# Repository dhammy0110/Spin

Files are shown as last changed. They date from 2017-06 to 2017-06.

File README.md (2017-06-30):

# Spin Turntable with AccelStepper motor control

Based off of the Spin project from Tiffany Tseng (https://github.com/ttseng/Spin), this fork contains the following changes:
// replaced motor driver with smoother AccelStepper movements
// deleted vestigial code and moved created rotateAndPhoto method to clean up main loop
// replaced Processing debug with native Arduino serial interface
// tuned controller to work with Spin ios app as it is.
// added Easy Button button switch to circuit schematic

If you wish to build, please check out the great instructions at the original project site http://spin.media.mit.edu/

## Arduino

This folder contains the SoftModem & AccelStepper libraries needed for the spin.ino Arduino sketch.  The spin sketch should be uploaded to the Arduino Uno running the Spin app.

## CAD

If you are building a turntable and have access to a laser cutter with a bed larger than 12", build the DEFAULT turntable. If you have a smaller laser cutter that cannot cut material larger than 12", build the Modified 12-inch turntable design.  Both designs have the same exact footprint (13"), but the modified 12-inch turntable has smaller laser cut parts and has an additional set of three 3D printed feet.

Each contains three subfolders: _3D Print_, _Laser Cut_, and _Solidworks_.  Building your own Spin turntable requires laser cutting parts in 3/16" and 1/8" acrylic, which can be found in the _Laser Cut_ folder in Illustrator, Corel Draw, and DXF formats.  Additionally, you'll need to 3D print a gear (motor_gear.STL), which can be found in the _3D print_ folder.  Optionally, you can 3D print your own iOS device dock (which can be used with an iPhone 4/5/6 or iPad/iPad mini).  If you are building the modified turntable, you will also need to 3D print three feet.  

You can find all the original CAD files in the _Solidworks_ folder.

## Electronics

The Eagle files and libraries for the original Spin shield are located here, as is the schematic for the DIY shield. You can purchase the shield directly from OSH Park: https://oshpark.com/profiles/scientiffic or solder your own DIY shield

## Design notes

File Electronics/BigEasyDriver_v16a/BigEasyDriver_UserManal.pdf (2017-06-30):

# Big Easy Driver User Manual

Doc version 1.2, for BED v1.2 11/04/2012
Brian Schmalz
Schmalz Haus LLC
www.schmalzhaus.com/BigEasyDriver brian@schmalzhaus.com

### Description

The Big Easy Driver (BED) is a major revision of the Easy Driver stepper driver board. The BED takes power and control signals (STEP and DIRECTION) and produces the signals necessary to step a 0A to 2Amp bi-polar stepper motor. The BED uses an Allegro A4983 or A4988 driver chip.

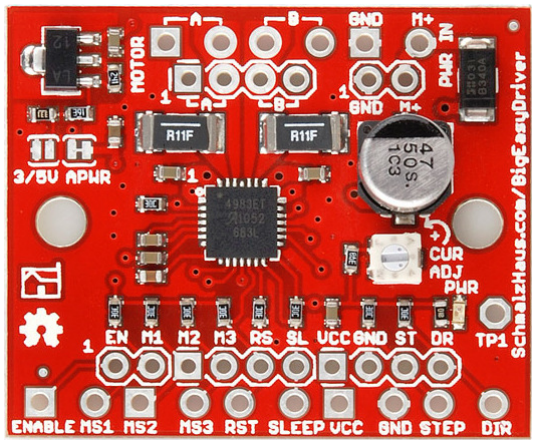
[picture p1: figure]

Figure 1: Big Easy Driver v1.2

### Hook Up

The BED has holes for both .100 headers as well as 3.5mm screw terminals. Either or both can be used to connect to the BED however you want. You can put female or male headers in the .100” holes or solder wires directly to the holes.

The minimum number of connections to the BED is 7 – four stepper wires, Power, Gnd and Step. All others are optional. Note that there are two ground connections – one next to the power input, and one next to the step input. Typically these will connect to the power supply ground and the signal ground (from the microcontroller) respectively.

Top Edge Connections

Motor: Connect the four wires from the motor to the four motor connections on the BED. The two “A” connections should connect to one coil, and the “B” connections to the other coil.

Power: Connect the power input (+8 to +30V filtered DC) to the M+ connection, and GND from the power supply to the GND connection.

Bottom Edge Connections
ENABLE: This input is pulled down on the board with a 20K Ohm resistor. You can leave it disconnected, or you can drive it from your microcontroller. When low, the driver chip is enabled and the motor is energized. When high, the driver chip is still enabled, but all of the final motor drive circuits are disabled and so no current will flow to the motor.

MS1, MS2, MS3: These inputs are all tied high with 20K Ohm resistors. They set the microstep setting. Use the following table to know how to control the microstep settings:
MS1 | MS2 | MS3 | Microstep Resolution | Excitation Mode
L | L | L | Full Step | 2 Phase
H | L | L | Half Step | 1-2 Phase
L | H | L | Quarter Step | W1-2 Phase
H | H | L | Either Step | 2W1-2 Phase
H | H | H | Sixteenth Step | 4W1-2 Phase

RST: (Reset) This input is tied high with a 20K Ohm resistor on the BED. If this signal is pulled low, the motor driver circuits are shut off, and the driver is reset. Only when this input is high will the driver chip enable the motor driver circuits and pay attention to the STEP input.

SLEEP: This input is tied high with a 20K Ohm resistor on the BED. To put the driver chip into a lower power mode (motor driver circuits shut off, charge pump shut down, etc.) pull this input low. When coming out of sleep, allow at least 1ms before sending STEP pulses.

VCC: This is an output from the BED’s voltage regulator. The voltage regulator takes the motor input voltage, and provides 5V (or 3.3V) for the logic inputs of the driver chip. You can normally use about 85mA from this pin, although the higher the motor input voltage is, the hotter the voltage regulator chip will get as you pull more current from this pin. See the jumper configuration section below to switch this to 3.3V output.

GND: This is one of two ground connections on the BED. The other is on the topside next to the M+ power input. Both grounds are internally tied together on the BED. This is a good place to tie the ground of your microcontroller.

STEP: This input is tied high with a 20K Ohm resistor on the BED. Each rising edge of this input will cause the stepper driver to advance one step in the direction specified by the DIR input. The STEP input must be high for at least 1us, and low for at least 1us.

DIR: This input is tied high with a 20K Ohm resistor on the BED. When a STEP pulse is received, the driver chip looks at this input to determine which direction to take the step. When high, the motor will turn counterclockwise, and when low, the motor will turn clockwise.

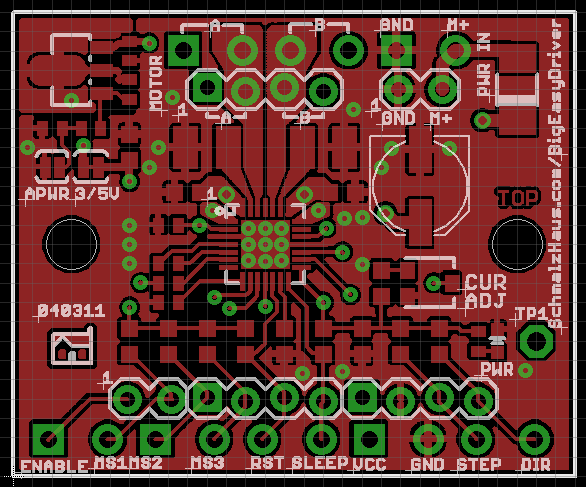
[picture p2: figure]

Figure 2: BED v1.1 Connection Placement Diagram

### Jumper Configuration

There are two jumpers on the BED – APWR (Alternate Power) and 3/5V. They are located in the upper left corner of the BED.

NOTE: On the v1.1 of the BED these two jumpers have their silk screen labels reversed.

APWR (Alternate Power) – This jumper is normally closed (connected). If you cut the trace between the two pads, the BED’s voltage regulator chip is disconnected from the circuit, and you can then use the VCC connection on the bottom edge of the board as an input, to power your BED with whatever logic level voltage you want to. (3.0V to 5.5V is the accepted range.) You might choose this option if you wish to power your BED’s logic level circuits with an external power source. This jumper is labeled SJ1 in the schematic.

3/5V – This jumper is normally open (dis-connected). You can switch the BED to use 3.3V for its logic level circuits by soldering this jumper closed. You would do this if you wanted to interface your BED to a 3.3V microcontroller for example. This jumper is labeled JS2 in the schematic.

### Current Limit Set Potentiometer

The BED includes a very small pot to allow for the adjustment of the maximum current level through the windings of the motor. On the board, this pot is labeled CUR ADJ. Turning changes the Vref voltage into the A4988 driver chip, and thus changes the maximum current that the driver chip delivers to the motor coils. Note that on v1.2 BED boards the silk screen arrow indicating which direction increases current to the motor is backwards. Use TP1 to determine maximum and minimum current directions to be sure.

The TP1 testpoint can be used to measure the voltage on the CUR_REF net, which the driver chip uses to determine the maximum current through the motor. Use your volt meter to measure the voltage on TP1 with respect to GND as you turn the pot.

If your BED uses .22 ohm sense resistors (some v1.1 BEDs): The range of the pot produces maximum motor currents from around 0mA (fully clockwise) to 2.4A (fully counterclockwise).

If your BED uses .11 ohm sense resistors (all v1.2 and above BEDs): The range of the pot produces maximum motor currents from around 0mA (fully clockwise) to 5A (fully counterclockwise). Now, the driver can’t supply 5A, so the full range of the pot won’t be used. A Vref of 1.76V will result in a motor current of 2A.

The equasion for this relationship is
Itripmax = Vref/(8 * Rs)
Where Itripmax is the maximum current delivered to the motor, Vref is the voltage on TP1, and Rs is the sense resistor value.

### Power LED

There is a yellow LED near the lower left corner of the BED labeled PWR. This LED will light any time there is 5V or 3.3V being supplied to the driver chip. If this LED goes off while there is still power being applied to the M+ and GND power inputs, then the voltage regulator chip has either become too hot and shut down, or has detected a short from VCC to GND and has shut off. If the LED turns on and off, then either the M+ power is turning on and off, or the voltage regulator chip is overheating and power cycling to try and stay cool

### Heat Dissipation

The Big Easy Driver can supply up to about 1.4A/phase of current at room temperature. This is due to the four layer construction of the board and the way the board is laid out. When driving high currents, the entire board will act as a heatsink, including the connectors and anything the board is connected to. The driver chip has excellent over temperature protection, so no damage can be done to the driver chip by running the board too hot – it will simply cut out until the chip temperature returns to normal (less than about 150C).

Adding a small heatsink (like Newark 43M6428) and/or using a small fan to cool the drive chip can allow currents in excess of 2A/phase.

### Motor Wiring

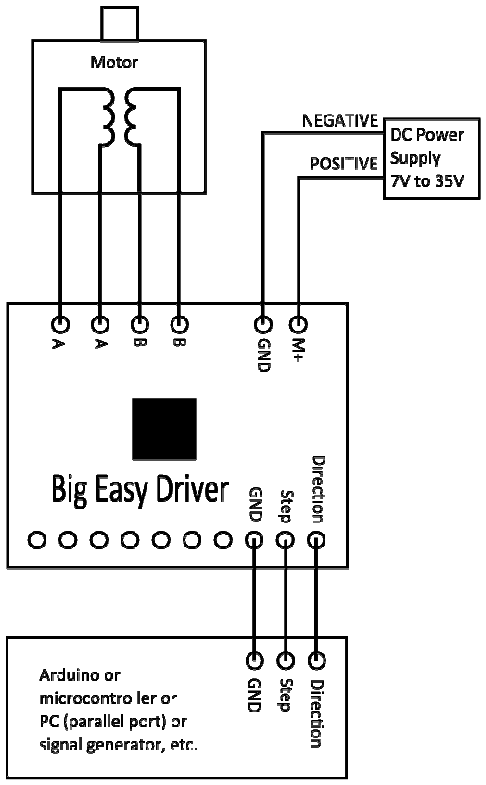
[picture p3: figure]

This diagram shows a typical connection (actually, the bare minimum connection) for a BED with a stepper motor and a source for step/direction signals. Of course, you can always connect more of the digital input signals on the BED (SLEEP, MS1, etc.) for more control.

### Specifications

The specifications of the Big Easy Driver are the same as for the Allegro A4983 or A4988 stepper driver chip (depending upon which is installed on the board). This includes a maximum of 2A/phase, 16th, 8th, ¼, ½ and full step modes, 3.3V or 5V logic inputs (jumper selectable).

### Schematic

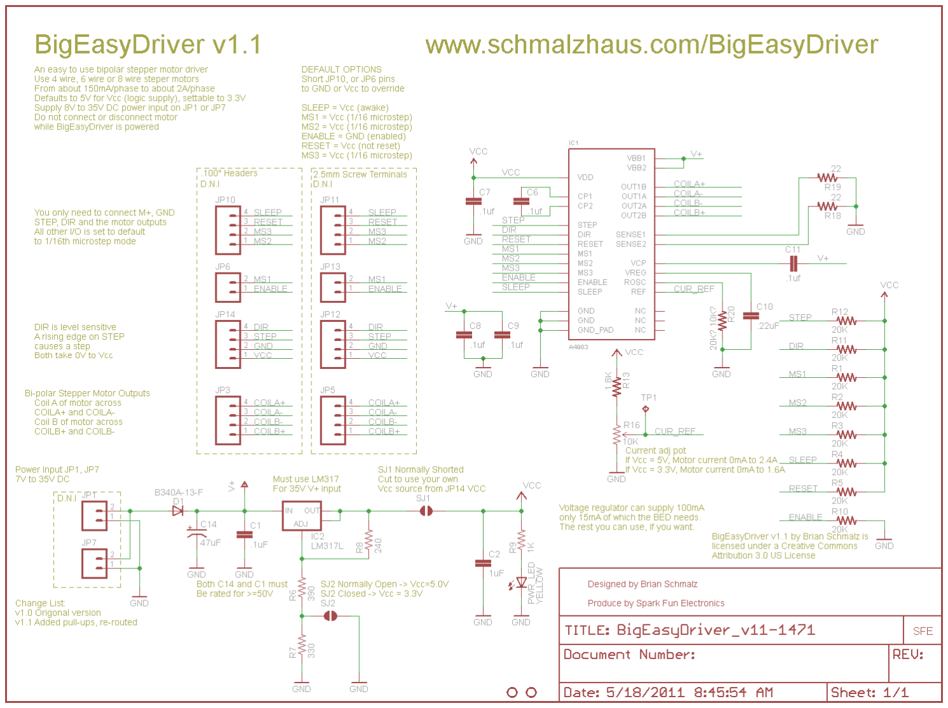
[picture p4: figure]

### Parts Placement

This user manual is only an overview. For more information about the technical details of how the BED drives the stepper motor, please see the official Allegro A4983 or A4988 driver datasheet. www.allegromicro.com

### License

This document, and the entire BED design, are released under the Creative Commons Attribution 3.0 US License. This means that you may use it for whatever purpose you want, including commercial use, but you MUST give the original author (Brian Schmalz) proper attribution.

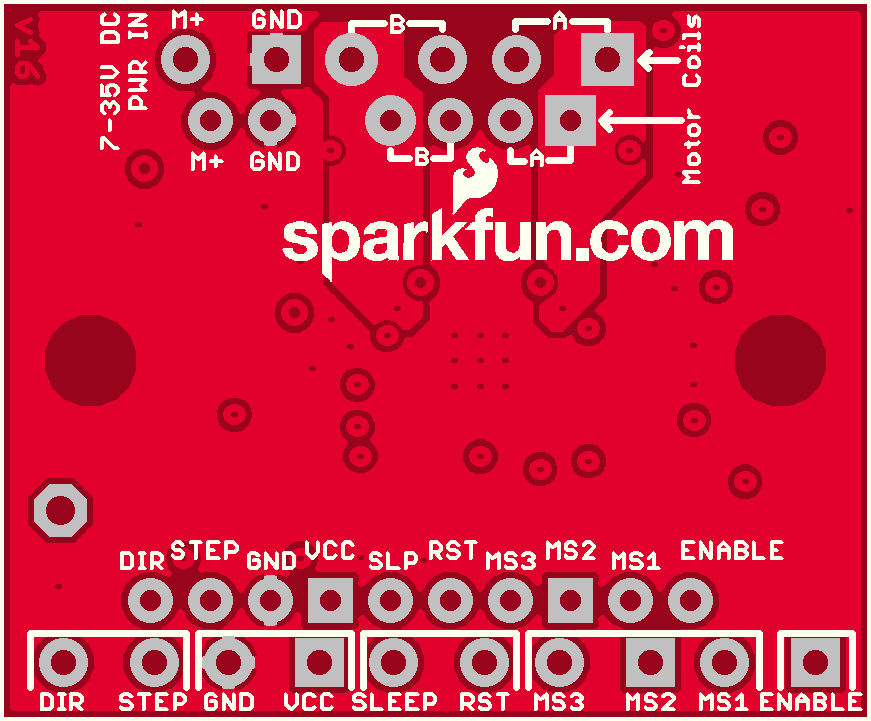
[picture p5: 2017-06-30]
Electronics/BigEasyDriver_v16a/BigEasyDriver_bottom_board.png

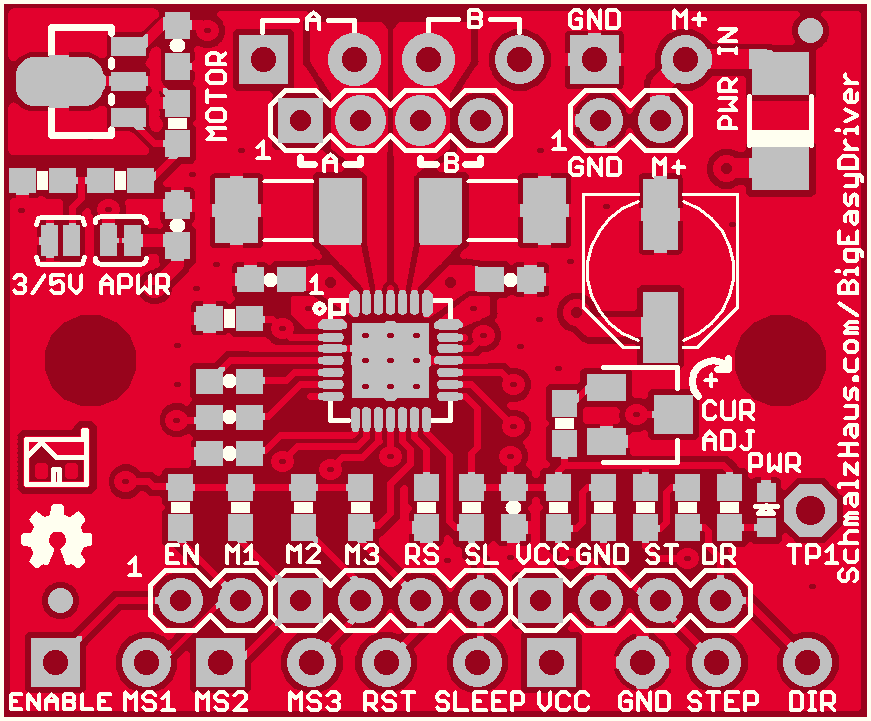
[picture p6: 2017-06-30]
Electronics/BigEasyDriver_v16a/BigEasyDriver_top_board.png

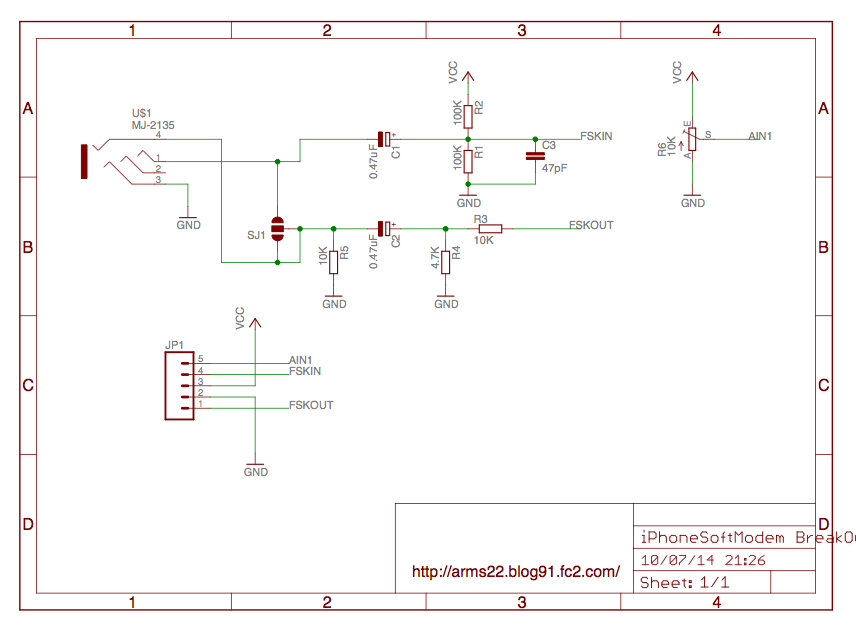
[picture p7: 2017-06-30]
Electronics/softmodem-circuit-schematic.png

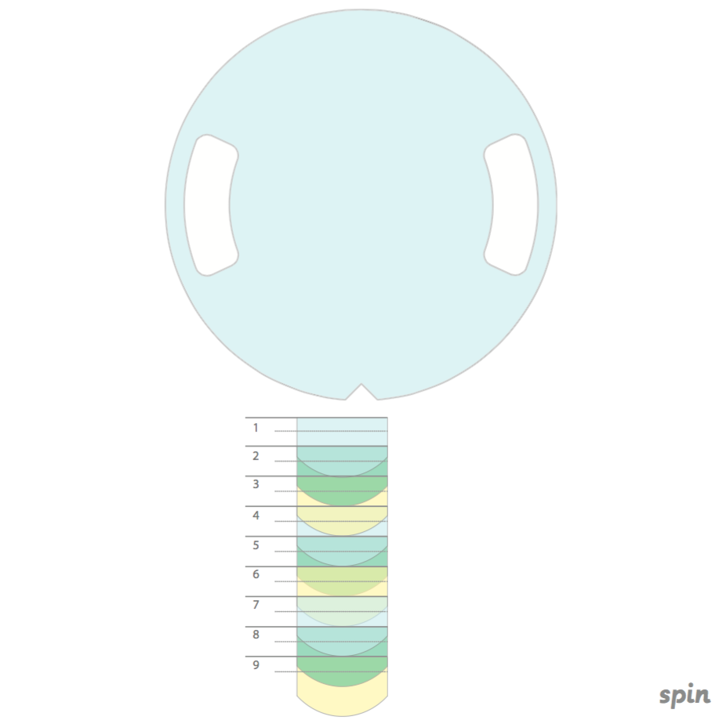
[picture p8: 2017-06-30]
CAD/Mat/mat.png

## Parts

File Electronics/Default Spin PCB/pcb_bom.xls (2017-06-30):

Item | Vendor | Quantity | Part Number | Total Price
Easy Drive Stepper Motor Driver | Sparkfun | 1 | ROB-12779 (https://www.sparkfun.com/products/12779) | 14.95
Blue LEDs 1206 SMD | Sparkfun | 1 (strip of 25) | PRT-12620 (https://www.sparkfun.com/products/12620) | 2.95
Male headers | Sparkfun | 2 | PRT-00116 (https://www.sparkfun.com/products/116) | 3
Female headers | Digikey | 1 | S5440-ND (http://www.digikey.com/product-detail/en/PPTC041LGBN-RC/S5440-ND/775898) | 0.63
3.5mm audio jack | Digikey | 1 | CP-43514-ND (http://www.digikey.com/product-search/en?KeyWords=CP-43514-ND&WT.z_header=search_go) | 1.18
100 Ω resistor 1206 SMD | Digikey | 4 | 311-100FRCT-ND (http://www.digikey.com/product-detail/en/0/311-100FRCT-ND) | 0.45
1 kΩ resistor 1206 SMD | Digikey | 2 | P1.0KECT-ND (http://www.digikey.com/product-detail/en/ERJ-8GEYJ102V/P1.0KECT-ND/203248) | 0.09
10 kΩ resistor 1206 SMD | Digikey | 1 | 311-10.0KFRCT-ND (http://www.digikey.com/product-detail/en/RC1206FR-0710KL/311-10.0KFRCT-ND/731430) | 0.09
0.22 µF 1206 capacitor | Digikey | 1 | 399-1251-1-ND (http://www.digikey.com/product-search/en?KeyWords=399-1251-1-ND&WT.z_header=search_go) | 0.17
 |  |  |  | Total: $23.51

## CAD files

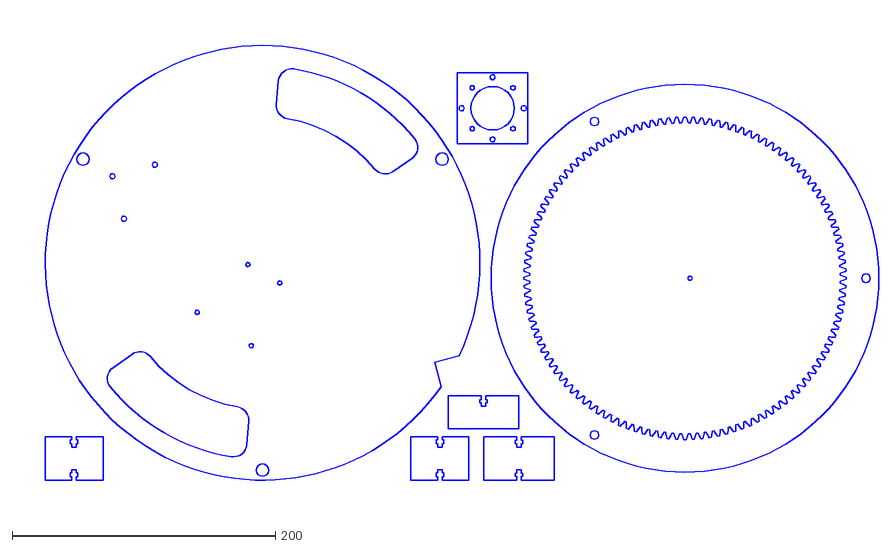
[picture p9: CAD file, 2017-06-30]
CAD/DEFAULT turntable/Laser Cut/SpinSmoothly-rearranged.dxf
655.5 x 374.2

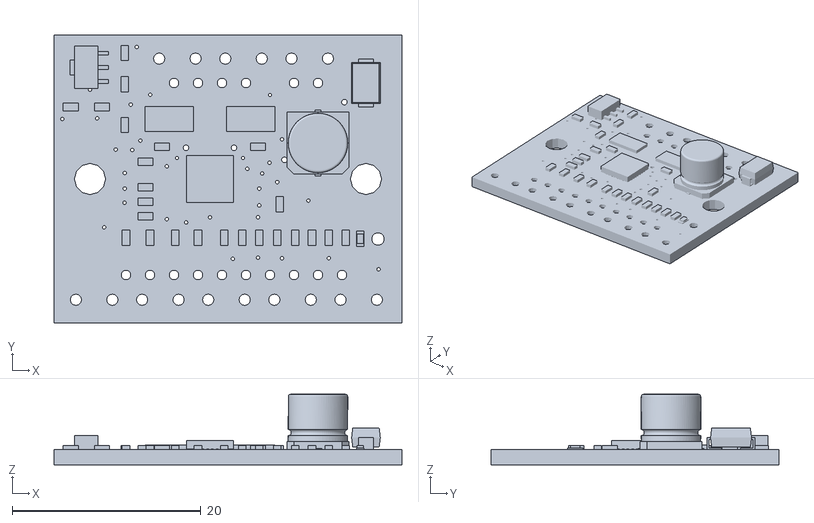
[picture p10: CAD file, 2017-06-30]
Electronics/BigEasyDriver_v16a/BigEasyDriver.stl
36.8 x 30.5 x 7.47

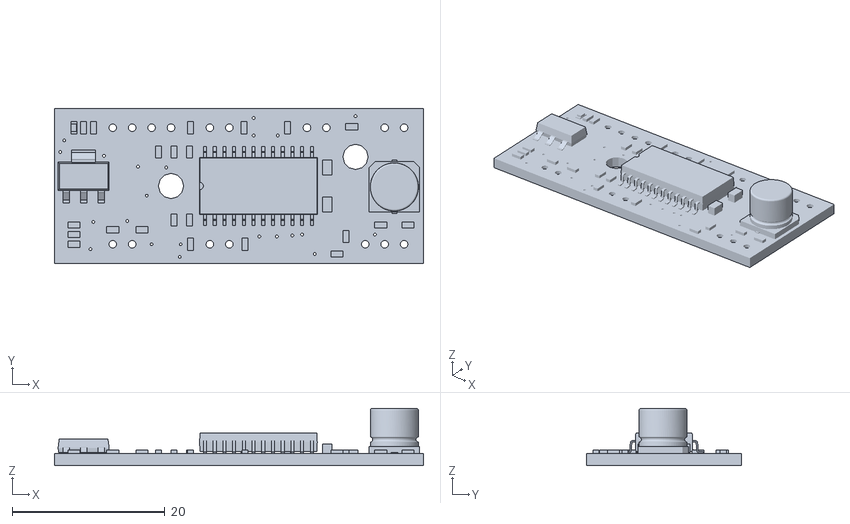
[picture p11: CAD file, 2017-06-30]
Electronics/Easy Driver/EasyDriver_v45-3DModel.stl
48.3 x 20.3 x 7.47

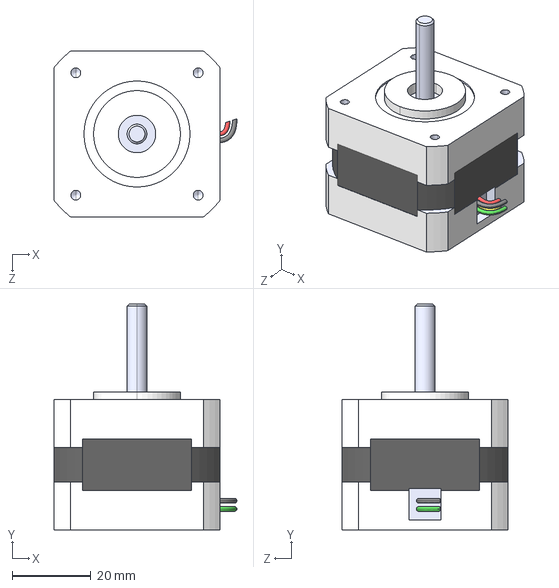
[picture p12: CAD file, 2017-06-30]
Electronics/Mercury Stepper Motor SM-42BYG011-25/Mercury Stepper Motor SM-42BYG011-25.STEP
46.3 x 57.2 x 42.0 mm

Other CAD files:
Electronics/BigEasyDriver_v16a/BigEasyDriver.blend
Electronics/BigEasyDriver_v16a/BigEasyDriver.skp
Electronics/Easy Driver/EasyDriver_v45-3DModel.skp
Electronics/Mercury Stepper Motor SM-42BYG011-25/Mercury Stepper Motor SM-42BYG011-25.IGS
Electronics/Mercury Stepper Motor SM-42BYG011-25/Mercury Stepper Motor SM-42BYG011-25.blend
Electronics/Mercury Stepper Motor SM-42BYG011-25/Mercury Stepper Motor SM-42BYG011-25.stl

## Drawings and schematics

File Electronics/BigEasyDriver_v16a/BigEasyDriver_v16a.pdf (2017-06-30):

# BigEasyDriver v1.6a

# www.schmalzhaus.com/BigEasyDriver

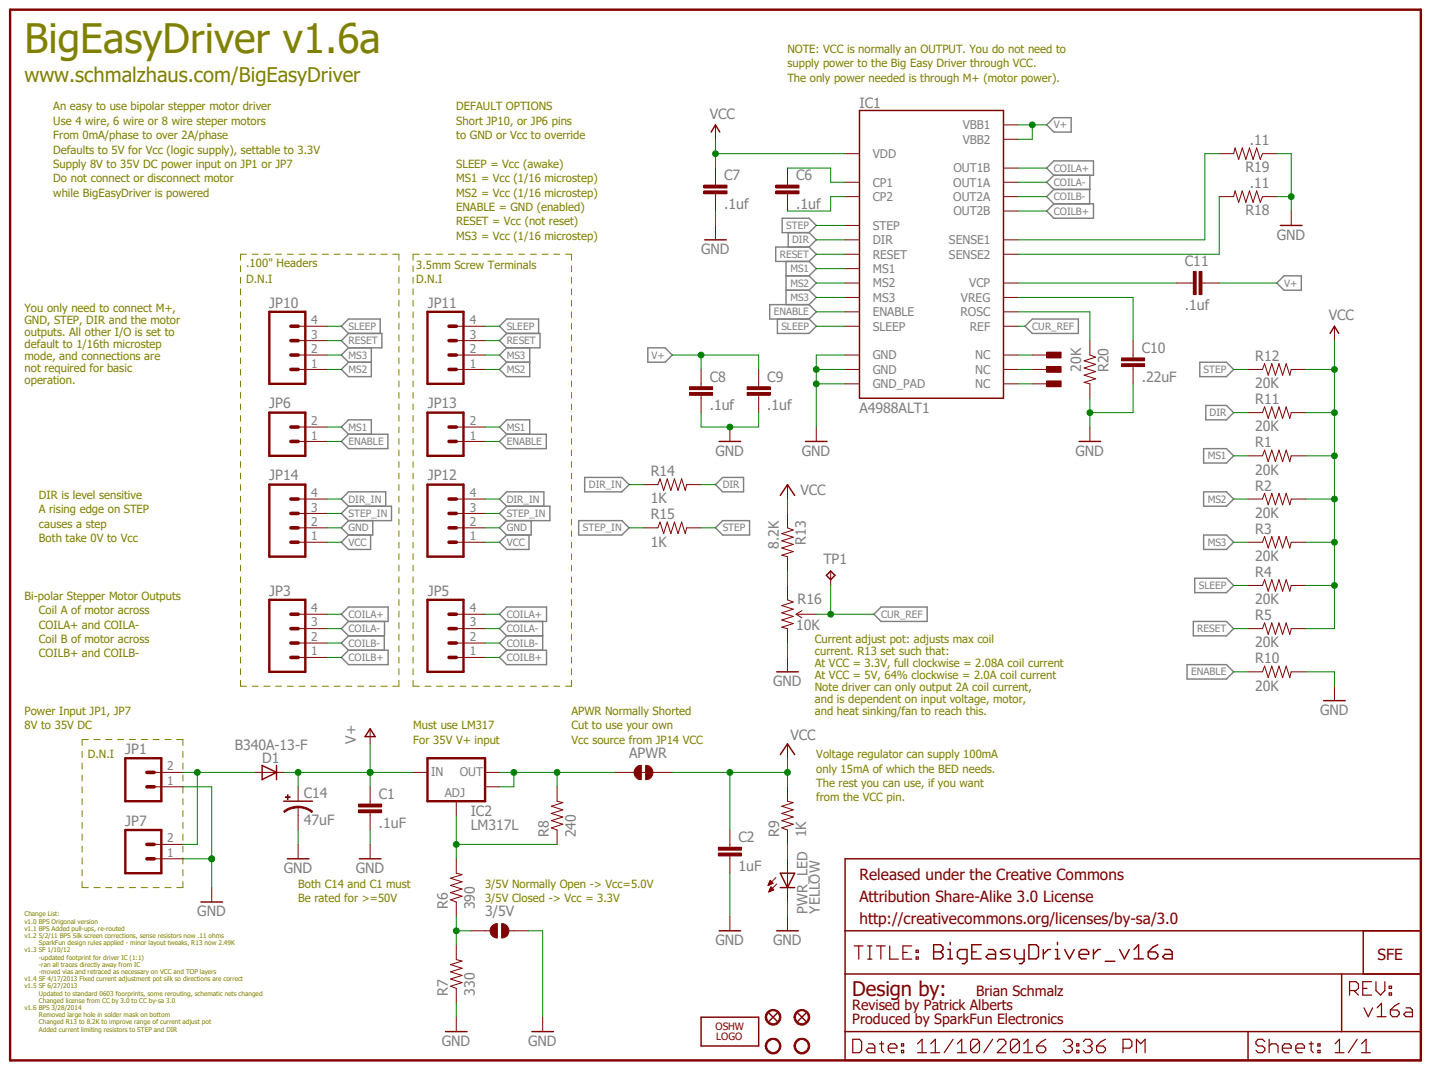
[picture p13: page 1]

NOTE: VCC is normally an OUTPUT. You do not need to
supply power to the Big Easy Driver through VCC.
The only power needed is through M+ (motor power).

An easy to use bipolar stepper motor driver
Use 4 wire, 6 wire or 8 wire steper motors
From 0mA/phase to over 2A/phase
Defaults to 5V for Vcc (logic supply), settable to 3.3V
Supply 8V to 35V DC power input on JP1 or JP7
Do not connect or disconnect motor
while BigEasyDriver is powered

DEFAULT OPTIONS
Short JP10, or JP6 pins
to GND or Vcc to override

SLEEP = Vcc (awake)
MS1 = Vcc (1/16 microstep)
MS2 = Vcc (1/16 microstep)
ENABLE = GND (enabled)
RESET = Vcc (not reset)
MS3 = Vcc (1/16 microstep)

You only need to connect M+,
GND, STEP, DIR and the motor
outputs. All other I/O is set to
default to 1/16th microstep
mode, and connections are
not required for basic
operation.

DIR is level sensitive
A rising edge on STEP
causes a step
Both take 0V to Vcc

Bi-polar Stepper Motor Outputs
Coil A of motor across
COILA+ and COILA-
Coil B of motor across
COILB+ and COILB-

Current adjust pot: adjusts max coil
current. R13 set such that:
At VCC = 3.3V, full clockwise = 2.08A coil current
At VCC = 5V, 64% clockwise = 2.0A coil current
GND

Note driver can only output 2A coil current,
and is dependent on input voltage, motor,
and heat sinking/fan to reach this.
VCC

APWR Normally Shorted
Cut to use your own
Vcc source from JP14 VCC

Voltage regulator can supply 100mA
only 15mA of which the BED needs.
The rest you can use, if you want
from the VCC pin.

Released under the Creative Commons
Attribution Share-Alike 3.0 License
http://creativecommons.org/licenses/by-sa/3.0

Change List:
v1.0 BPS Origonal version
v1.1 BPS Added pull-ups, re-routed
v1.2 5/2/11 BPS Silk screen corrections, sense resistors now .11 ohms
SparkFun design rules applied - minor layout tweaks, R13 now 2.49K
-updated footprint for driver IC (1:1)
-ran all traces directly away from IC
-moved vias and retraced as necessary on VCC and TOP layers
v1.4 SF 4/17/2013 Fixed current adjustment pot silk so directions are correct
Updated to standard 0603 foorprints, some rerouting, schematic nets changed
Changed license from CC by 3.0 to CC by-sa 3.0
v1.6 BPS 3/28/2014
Removed large hole in solder mask on bottom
Changed R13 to 8.2K to improve range of current adjust pot
Added current limiting resistors to STEP and DIR

SFE

Design by: Brian Schmalz Revised by Patrick Alberts Produced by SparkFun Electronics

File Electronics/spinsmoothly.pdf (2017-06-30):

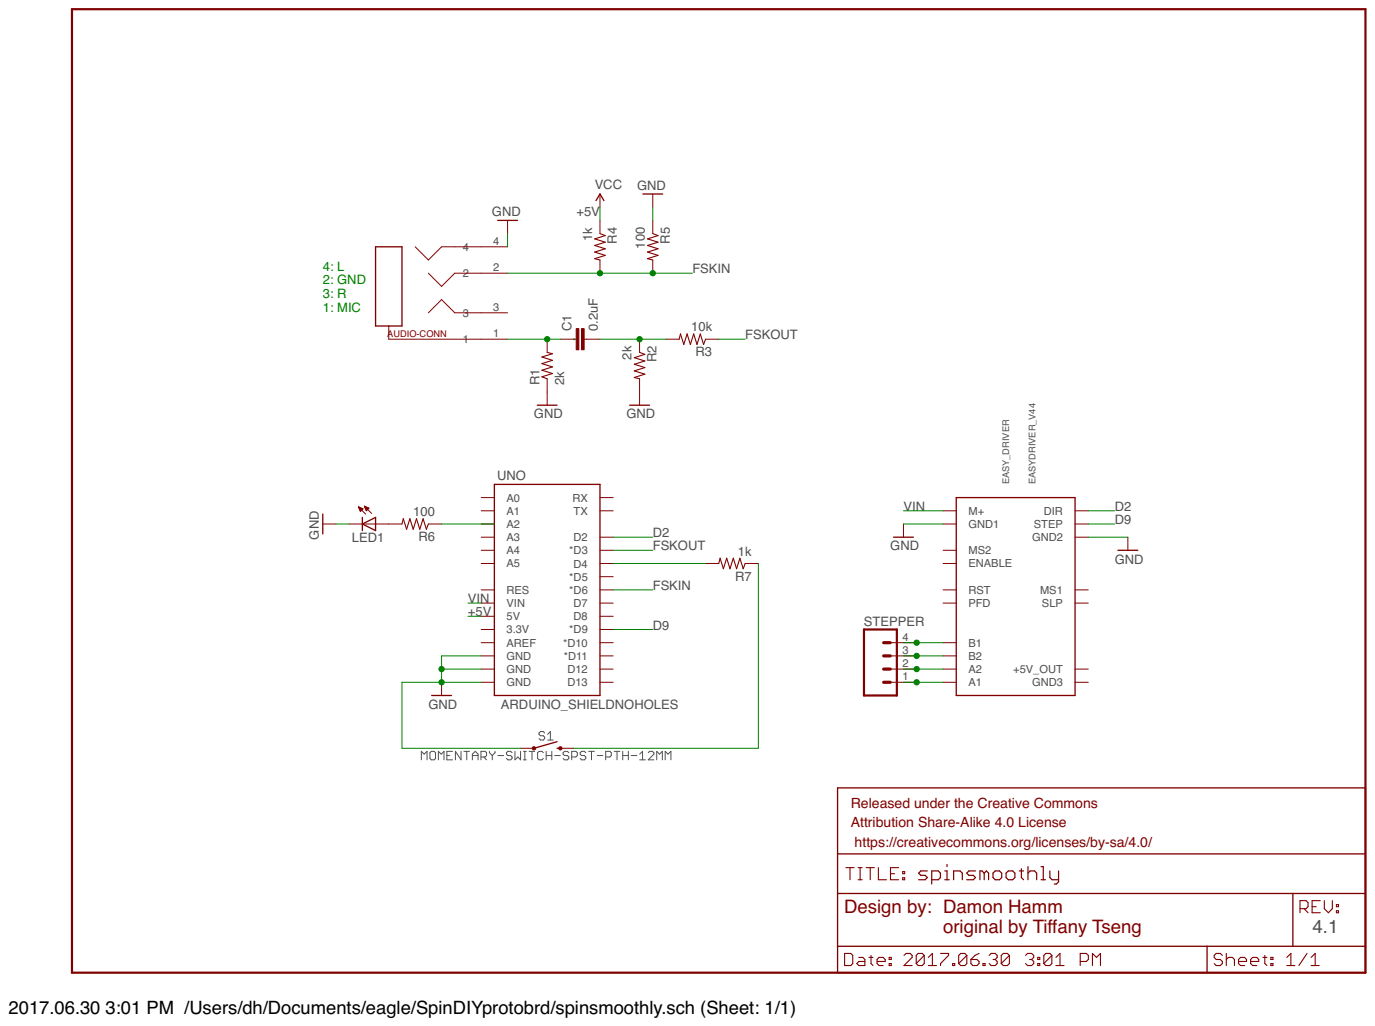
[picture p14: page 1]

Released under the Creative Commons Attribution Share-Alike 4.0 License

https://creativecommons.org/licenses/by-sa/4.0/

Damon Hamm
original by Tiffany Tseng

2017.06.30 3:01 PM /Users/dh/Documents/eagle/SpinDIYprotobrd/spinsmoothly.sch (Sheet: 1/1)

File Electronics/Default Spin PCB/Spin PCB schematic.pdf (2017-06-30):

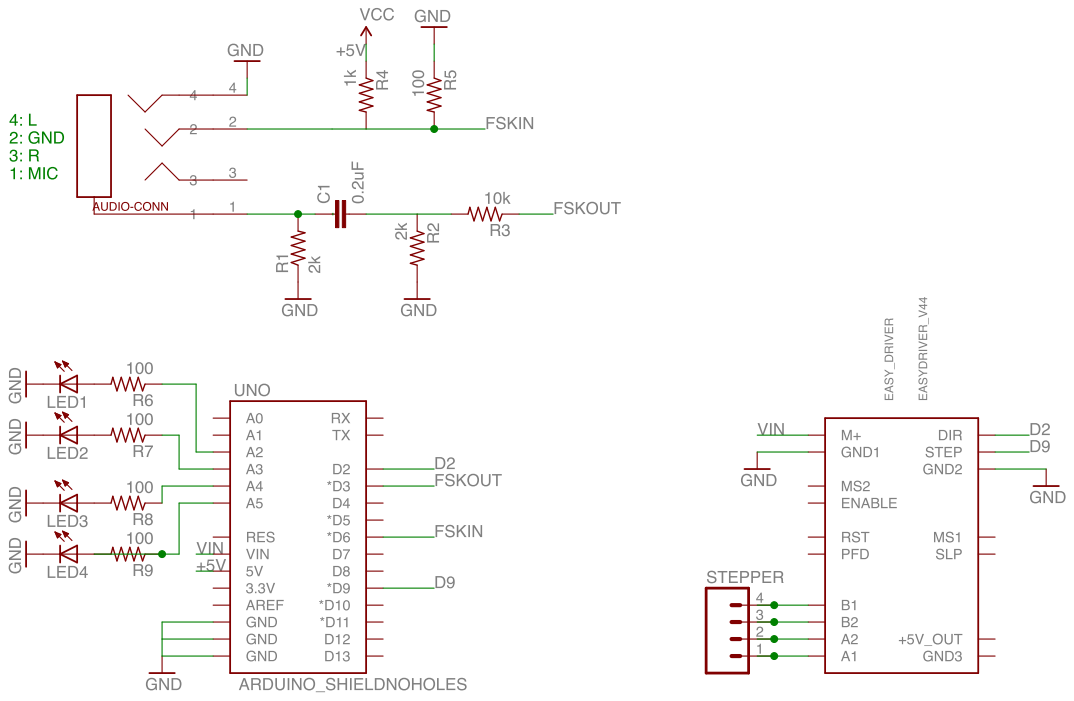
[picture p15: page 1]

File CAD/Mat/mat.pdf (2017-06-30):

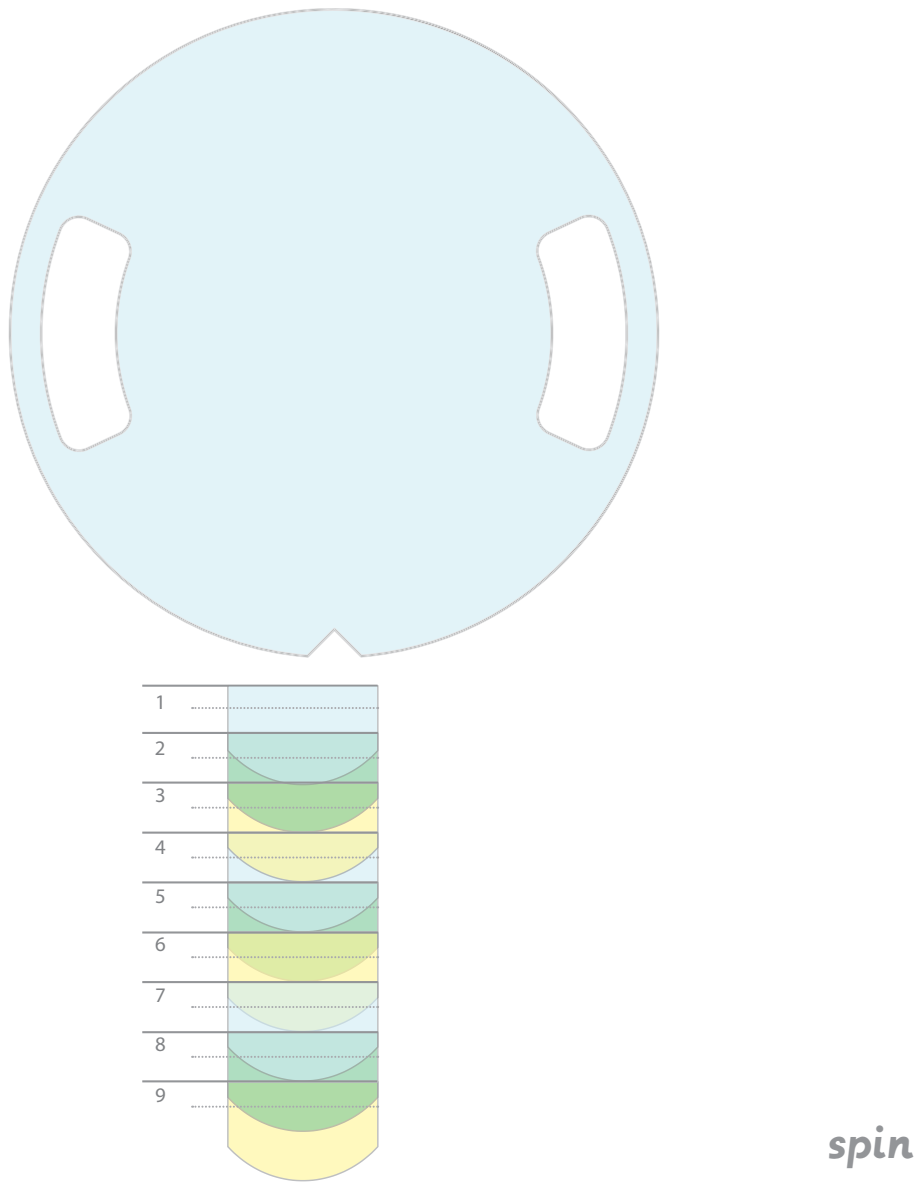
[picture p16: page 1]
spin

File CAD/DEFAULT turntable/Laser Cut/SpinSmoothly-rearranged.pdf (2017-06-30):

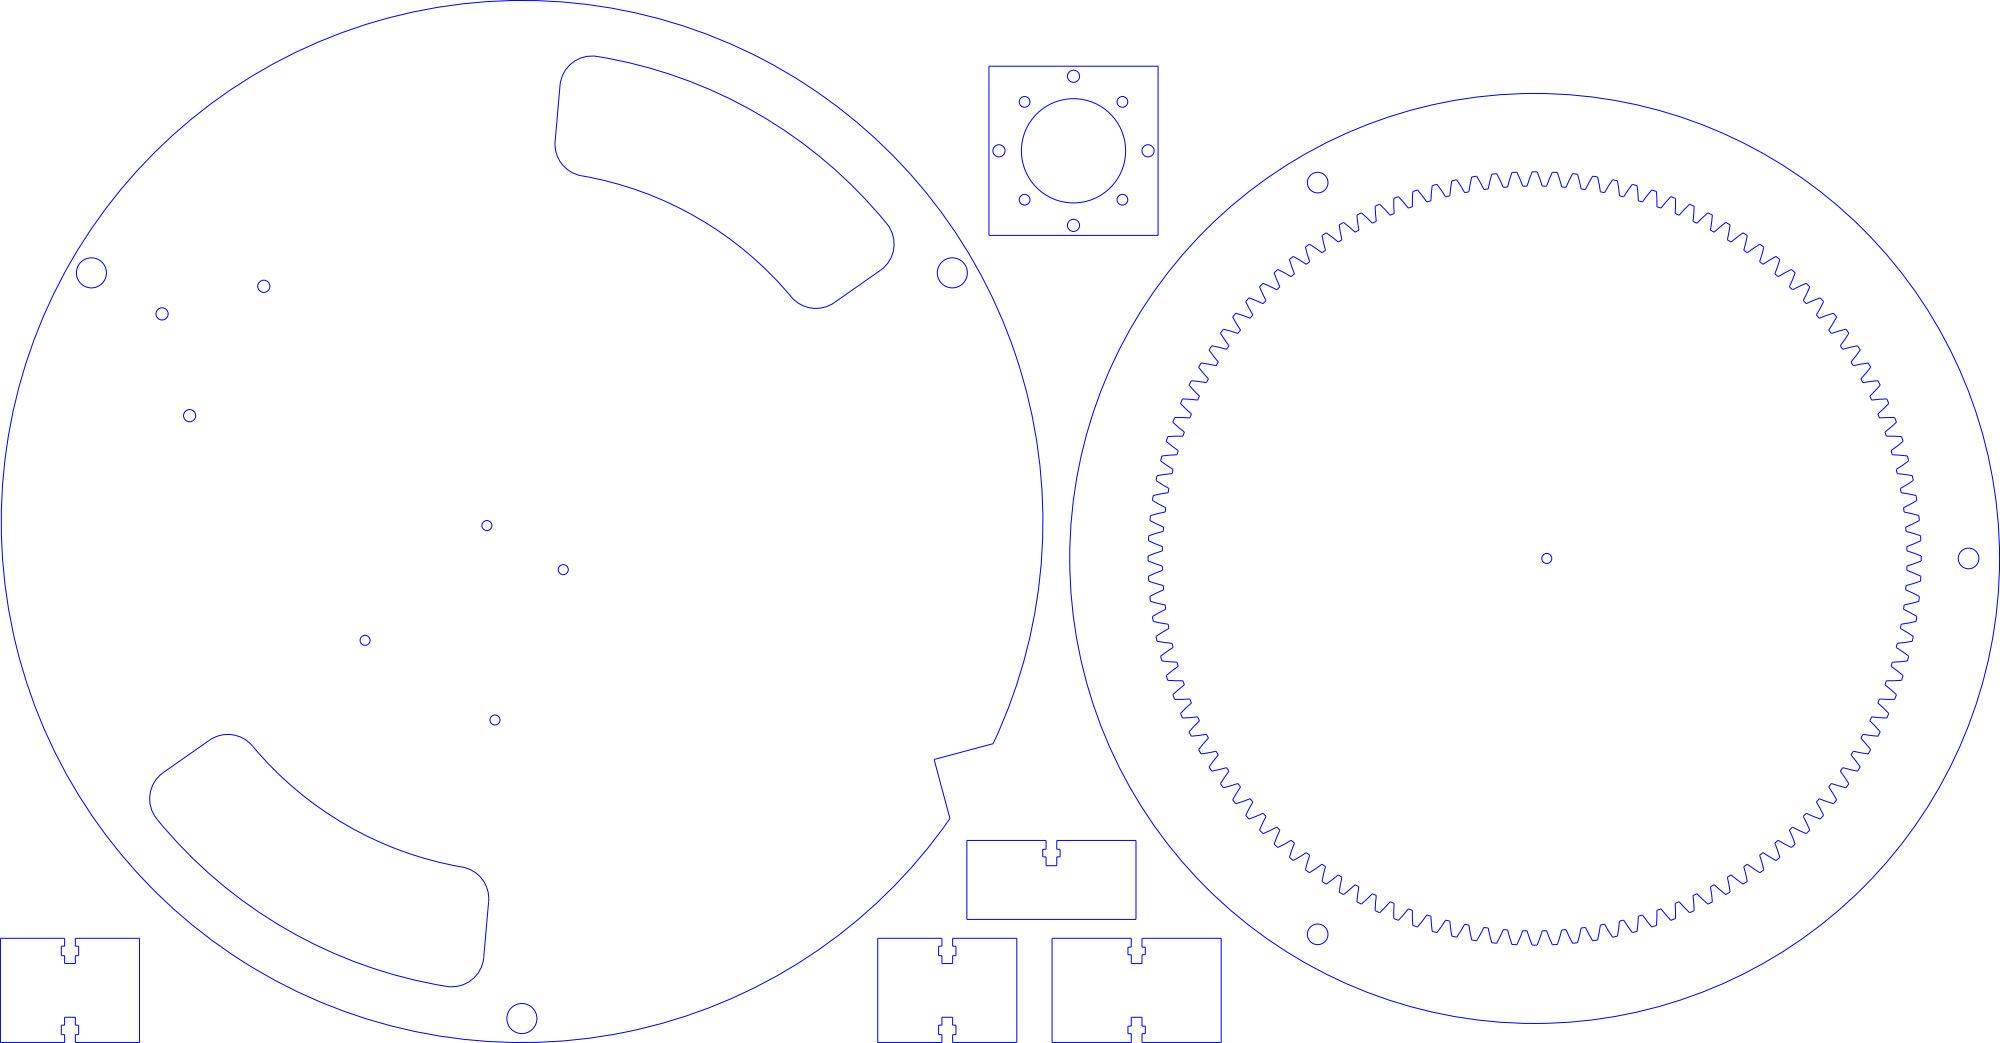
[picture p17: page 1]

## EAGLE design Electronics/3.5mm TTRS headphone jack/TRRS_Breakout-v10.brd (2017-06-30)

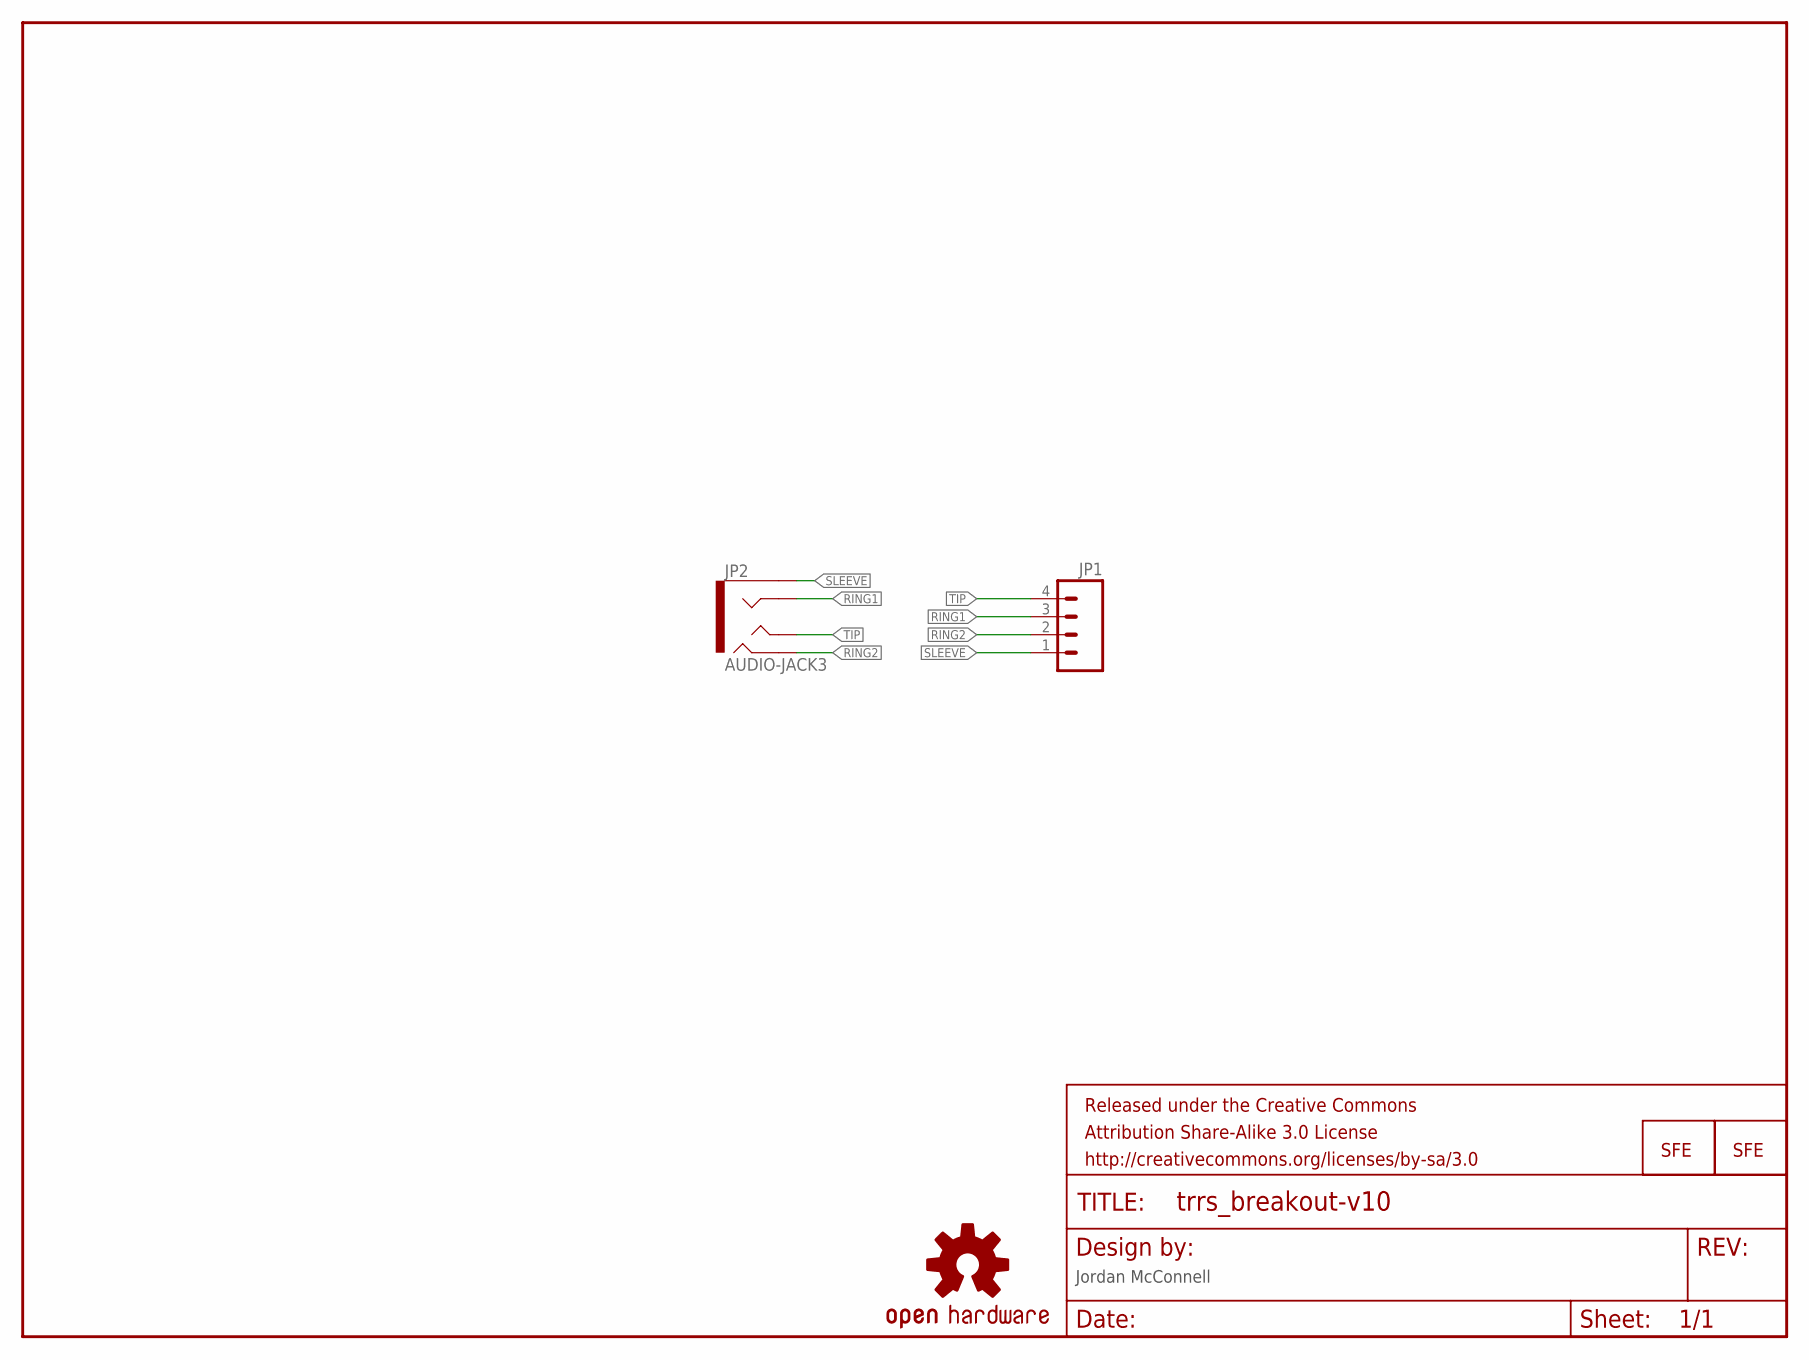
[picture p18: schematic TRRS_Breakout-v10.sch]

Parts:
FRAME1: FRAME-LETTER; CREATIVE_COMMONS
JP1: M04PTH; 1X04
JP2: AUDIO-JACK3; AUDIO-JACK-TRRS-SMD
JP3, JP4: LOGO-SFESK; SFE-LOGO-FLAME
U$1: OSHW-LOGOS; OSHW-LOGO-S

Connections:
RING1: JP1.3, JP2.RING1
RING2: JP1.2, JP2.RING2
SLEEVE: JP1.1, JP2.EARTH
TIP: JP1.4, JP2.TIP

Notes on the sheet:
Jordan McConnell

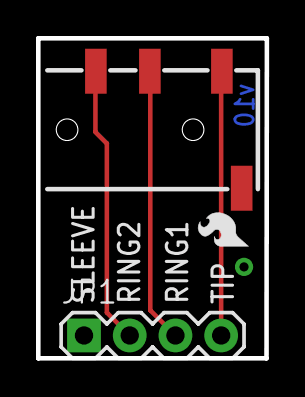
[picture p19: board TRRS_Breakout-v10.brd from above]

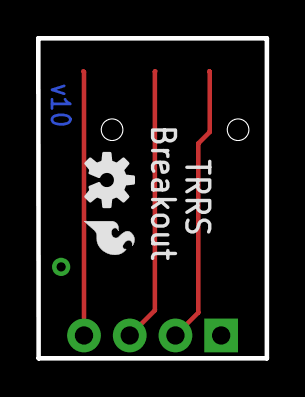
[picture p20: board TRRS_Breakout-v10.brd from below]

Board: 2 copper layers, 12.7 x 17.8 mm, 6 parts (2 on the bottom side), 4 nets.

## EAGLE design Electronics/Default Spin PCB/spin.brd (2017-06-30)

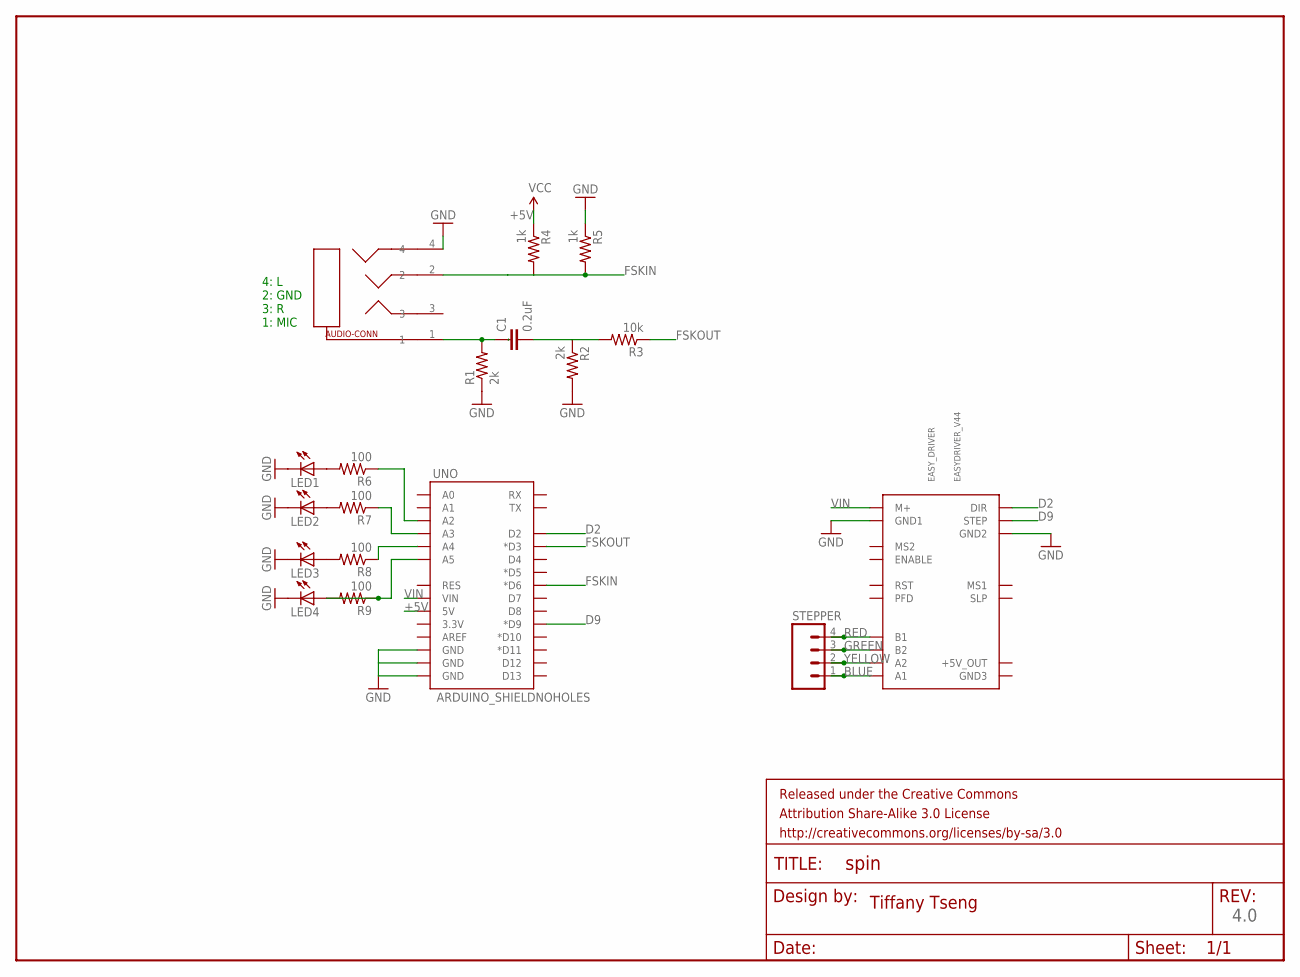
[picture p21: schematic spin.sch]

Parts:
C1: 0.2uF; 1206
EASY_DRIVER: EASYDRIVER_V44
FRAME1: FRAME-LETTER; CREATIVE_COMMONS
LED1, LED2, LED3, LED4: LED1206; 1206
R1, R2: 2k; R1206
R3: 10k; R1206
R4, R5: 1k; R1206
R6, R7, R8, R9: 100; R1206
STEPPER: M04PTH; 1X04
U$1: SJ-43514
UNO: ARDUINO_SHIELDNOHOLES; DUEMILANOVE_SHIELD_NOHOLES

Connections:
1: C1.1, R1.2, U$1.1
+5V: R4.1, UNO.5V
BLUE: EASY_DRIVER.A1, STEPPER.1
D2: EASY_DRIVER.DIR, UNO.D2
D9: EASY_DRIVER.STEP, UNO.D9 (*D9)
FSKIN: R4.2, R5.2, U$1.2, UNO.D6 (*D6)
FSKOUT: R3.1, UNO.D3 (*D3)
GND: EASY_DRIVER.GND1, EASY_DRIVER.GND2, LED1.2 (C), LED2.2 (C), LED3.2 (C), LED4.2 (C), R1.1, R2.2, R5.1, U$1.4, UNO.GND@0 (GND), UNO.GND@1 (GND), UNO.GND@2 (GND)
GREEN: EASY_DRIVER.B2, STEPPER.3
unnamed: C1.2, R2.1, R3.2
unnamed: R9.1, UNO.A5
unnamed: LED1.1 (A), R6.2
unnamed: LED2.1 (A), R7.2
unnamed: R8.1, UNO.A4
unnamed: LED3.1 (A), R8.2
unnamed: R7.1, UNO.A3
unnamed: LED4.1 (A), R9.2
unnamed: R6.1, UNO.A2
RED: EASY_DRIVER.B1, STEPPER.4
VIN: EASY_DRIVER.M+, UNO.VIN
YELLOW: EASY_DRIVER.A2, STEPPER.2

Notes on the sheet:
4: L 2: GND 3: R 1: MIC
4.0
Tiffany Tseng

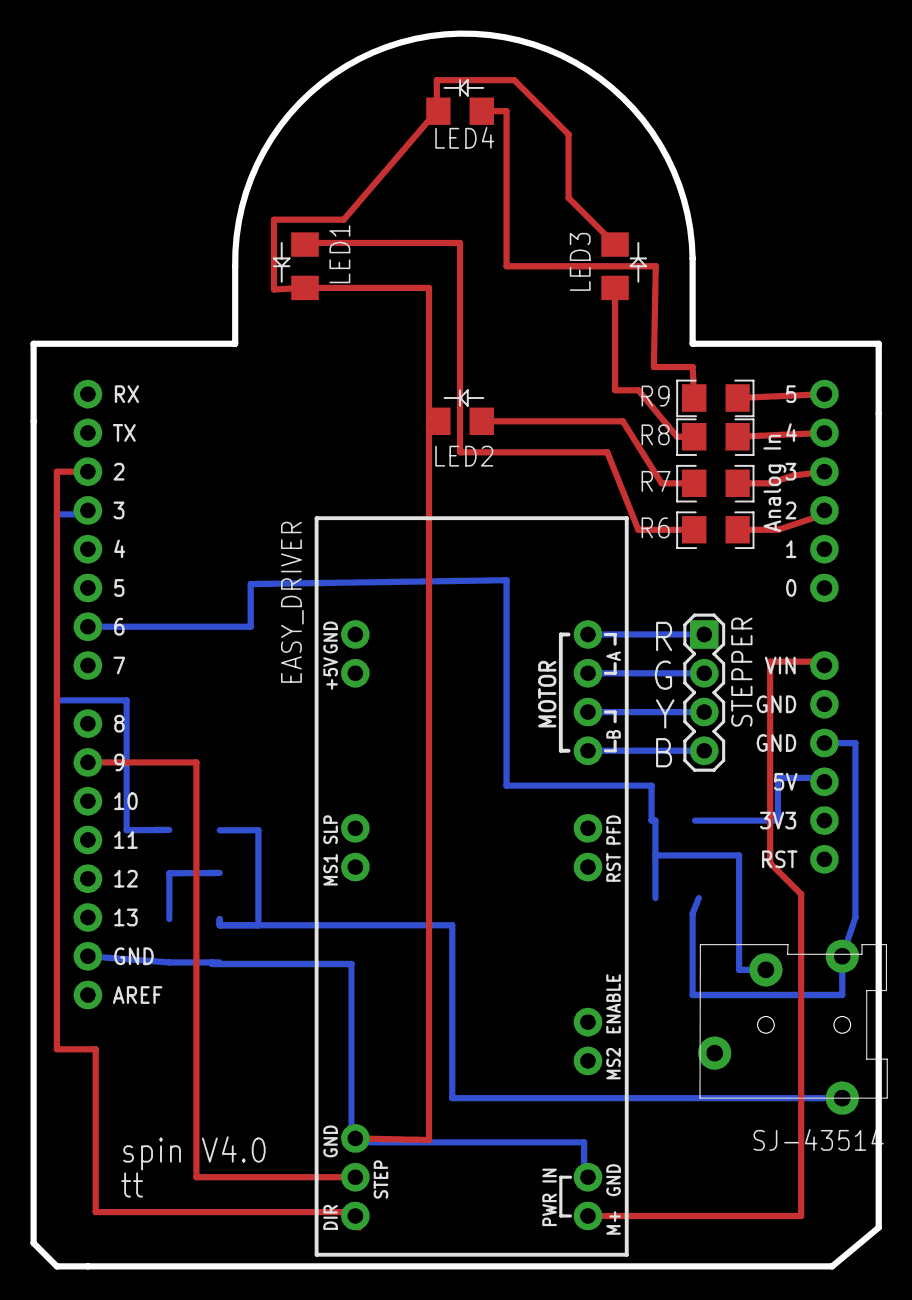
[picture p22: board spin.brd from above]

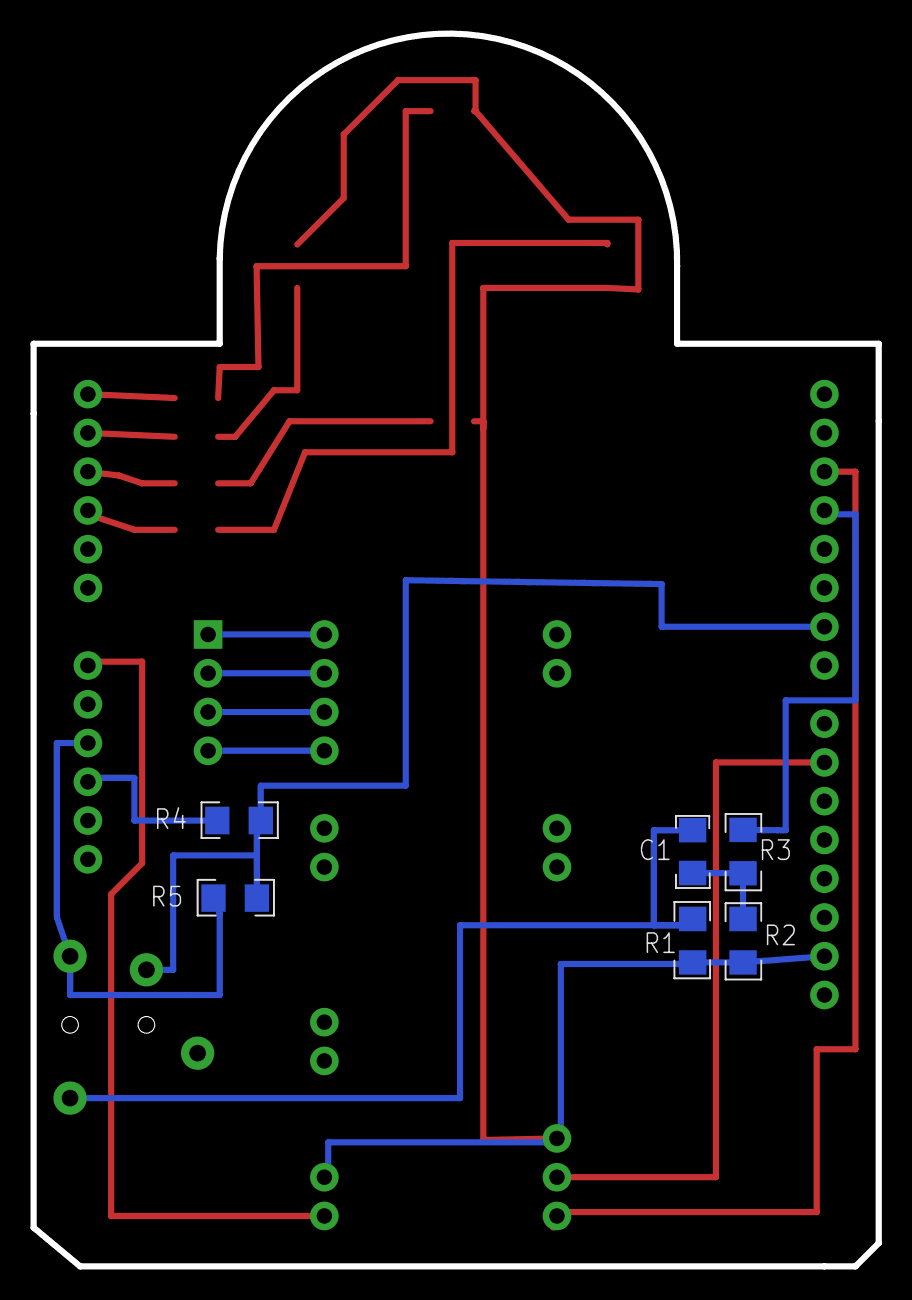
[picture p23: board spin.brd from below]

Board: 2 copper layers, 55.4 x 80.8 mm, 19 parts (6 on the bottom side), 21 nets.

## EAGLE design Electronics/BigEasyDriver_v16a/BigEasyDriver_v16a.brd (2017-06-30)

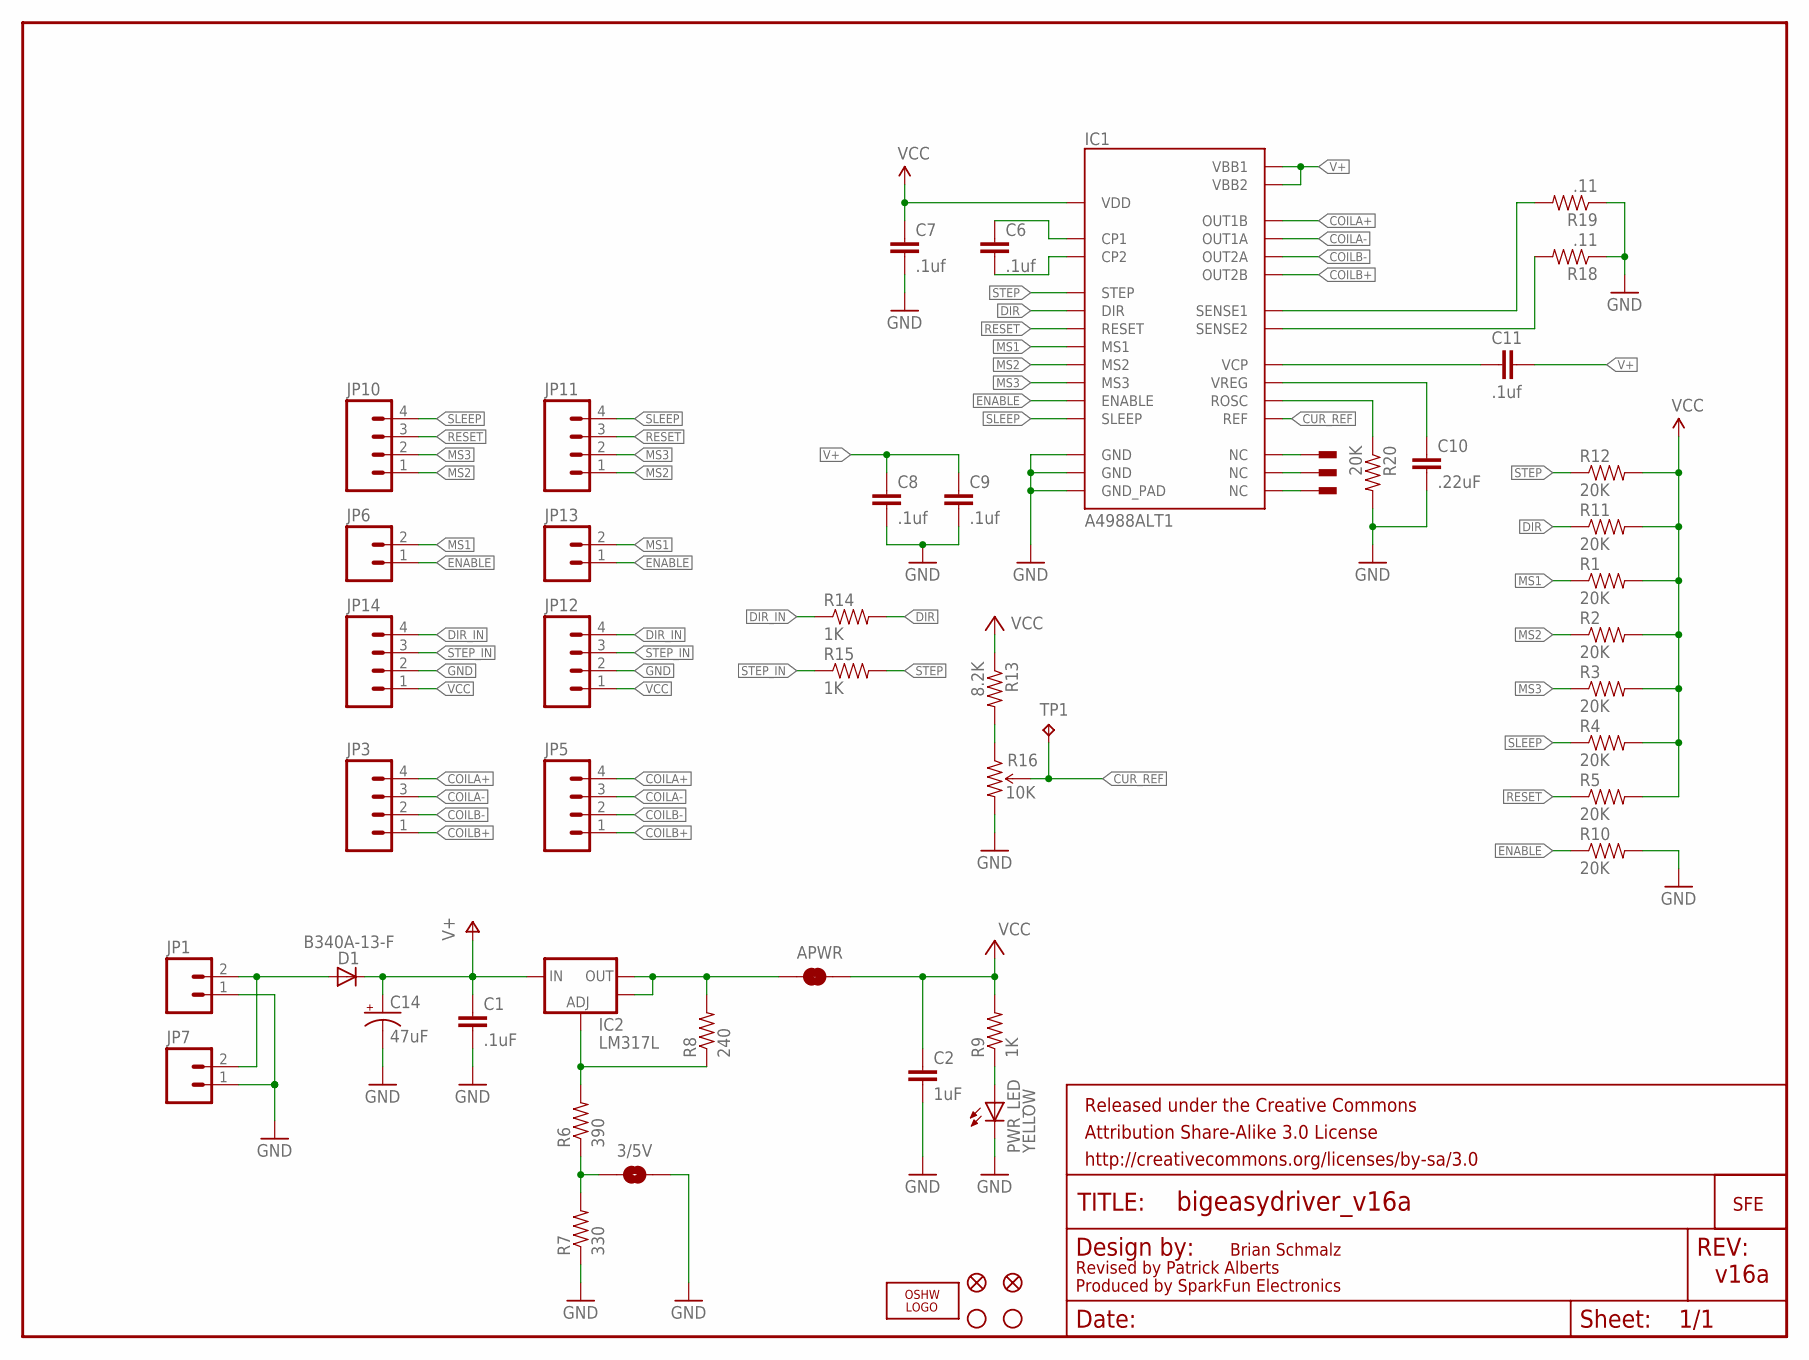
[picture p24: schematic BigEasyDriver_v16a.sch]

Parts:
3/5V: SOLDERJUMPERNO; SJ_2S-NO
APWR: SOLDERJUMPERTRACE; SJ_2S-TRACE
C1: .1uF; 0603-CAP
C2: 1uF; 0603-CAP
C6, C7, C8, C9, C11: .1uf; 0603-CAP
C10: .22uF; 0603-CAP
C14: 47uF; PANASONIC_D
D1: B340A-13-F; DO-214AC
FID1, FID2: FIDUCIAL1X2; FIDUCIAL-1X2
FRAME1: FRAME-LETTER; CREATIVE_COMMONS
IC1: A4988ALT1; QFN-28-5MM_ALT1
IC2: LM317L; SCHMALZHAUS_SOT89
JP1, JP6: M02PTH; 1X02
JP3, JP10, JP14: M04PTH; 1X04
JP5, JP11, JP12: M04SCREW_LOCK; SCREWTERMINAL-3.5MM-4_LOCK
JP7, JP13: M023.5MM_LOCK; SCREWTERMINAL-3.5MM-2_LOCK
JP8, JP9: STAND-OFF
LOGO1: OSHW_LOGO_FILLX0100-NT; OSHW_FILLX100_NOTEXT
PWR_LED: YELLOW; LED-0603
R1, R2, R3, R4, R5, R10, R11, R12, R20: 20K; 0603-RES
R6: 390; 0603-RES
R7: 330; 0603-RES
R8: 240; 0603-RES
R9, R14, R15: 1K; 0603-RES
R13: 8.2K; 0603-RES
R16: 10K; TRIMPOT-3MM-2
R18, R19: .11; R2010
TP1: TPPAD1-13; P1-13
U$2: LOGO-SFENEW; SFE-NEW-WEBLOGO
U$3, U$4, U$5: PAD; PAD-0.008

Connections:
5V_ALT: APWR.1, IC2.OUT, IC2.OUT@1 (OUT), R8.2
COILA+: IC1.P$21 (OUT1B), JP3.4, JP5.4
COILA-: IC1.P$24 (OUT1A), JP3.3, JP5.3
COILB+: IC1.P$1 (OUT2B), JP3.1, JP5.1
COILB-: IC1.P$26 (OUT2A), JP3.2, JP5.2
CUR_REF: IC1.P$17 (REF), R16.2 (WIPER), TP1.TP
DIR: IC1.P$19 (DIR), R11.1, R14.2
DIR_IN: JP12.4, JP14.4, R14.1
ENABLE: IC1.P$2 (ENABLE), JP6.1, JP13.1, R10.1
GND: 3/5V.2, C1.2, C2.2, C7.2, C8.2, C9.2, C10.2, C14.-, IC1.P$3 (GND), IC1.P$18 (GND), IC1.P$29 (GND_PAD), JP1.1, JP7.1, JP12.2, JP14.2, PWR_LED.C, R7.1, R10.2, R16.3 (CW), R18.1, R19.1, R20.2
MS1: IC1.P$9 (MS1), JP6.2, JP13.2, R1.1
MS2: IC1.P$10 (MS2), JP10.1, JP11.1, R2.1
MS3: IC1.P$11 (MS3), JP10.2, JP11.2, R3.1
unnamed: D1.A, JP1.2, JP7.2
unnamed: PWR_LED.A, R9.1
unnamed: R13.2, R16.1 (CCW)
unnamed: 3/5V.1, R6.1, R7.2
unnamed: IC1.P$7 (NC), U$3.P$1
unnamed: IC2.ADJ, R6.2, R8.1
unnamed: IC1.P$20 (NC), U$4.P$1
unnamed: C6.1, IC1.P$4 (CP1)
unnamed: C6.2, IC1.P$5 (CP2)
unnamed: IC1.P$25 (NC), U$5.P$1
unnamed: IC1.P$13 (ROSC), R20.1
unnamed: C10.1, IC1.P$8 (VREG)
unnamed: C11.1, IC1.P$6 (VCP)
unnamed: IC1.P$27 (SENSE2), R18.2
unnamed: IC1.P$23 (SENSE1), R19.2
RESET: IC1.P$12 (RESET), JP10.3, JP11.3, R5.1
SLEEP: IC1.P$14 (SLEEP), JP10.4, JP11.4, R4.1
STEP: IC1.P$16 (STEP), R12.1, R15.2
STEP_IN: JP12.3, JP14.3, R15.1
V+: C1.1, C8.1, C9.1, C11.2, C14.+, D1.C, IC1.P$22 (VBB1), IC1.P$28 (VBB2), IC2.IN
VCC: APWR.2, C2.1, C7.1, IC1.P$15 (VDD), JP12.1, JP14.1, R1.2, R2.2, R3.2, R4.2, R5.2, R9.2, R11.2, R12.2, R13.1

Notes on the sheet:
Brian Schmalz
Produced by SparkFun Electronics
v16a
Revised by Patrick Alberts

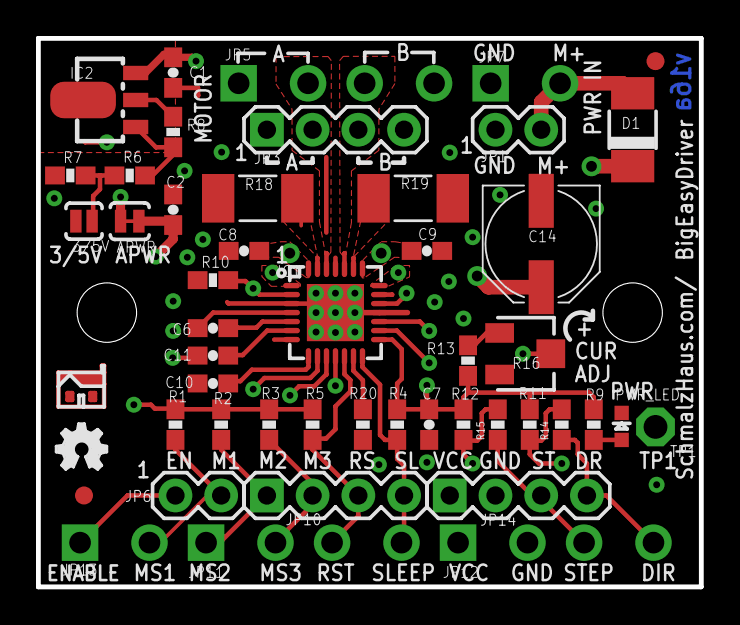
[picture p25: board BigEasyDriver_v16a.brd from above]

Board: 4 copper layers, 36.8 x 30.5 mm, 56 parts (1 on the bottom side), 34 nets.

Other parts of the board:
U$1: SCHMALZHAUS_SMALL

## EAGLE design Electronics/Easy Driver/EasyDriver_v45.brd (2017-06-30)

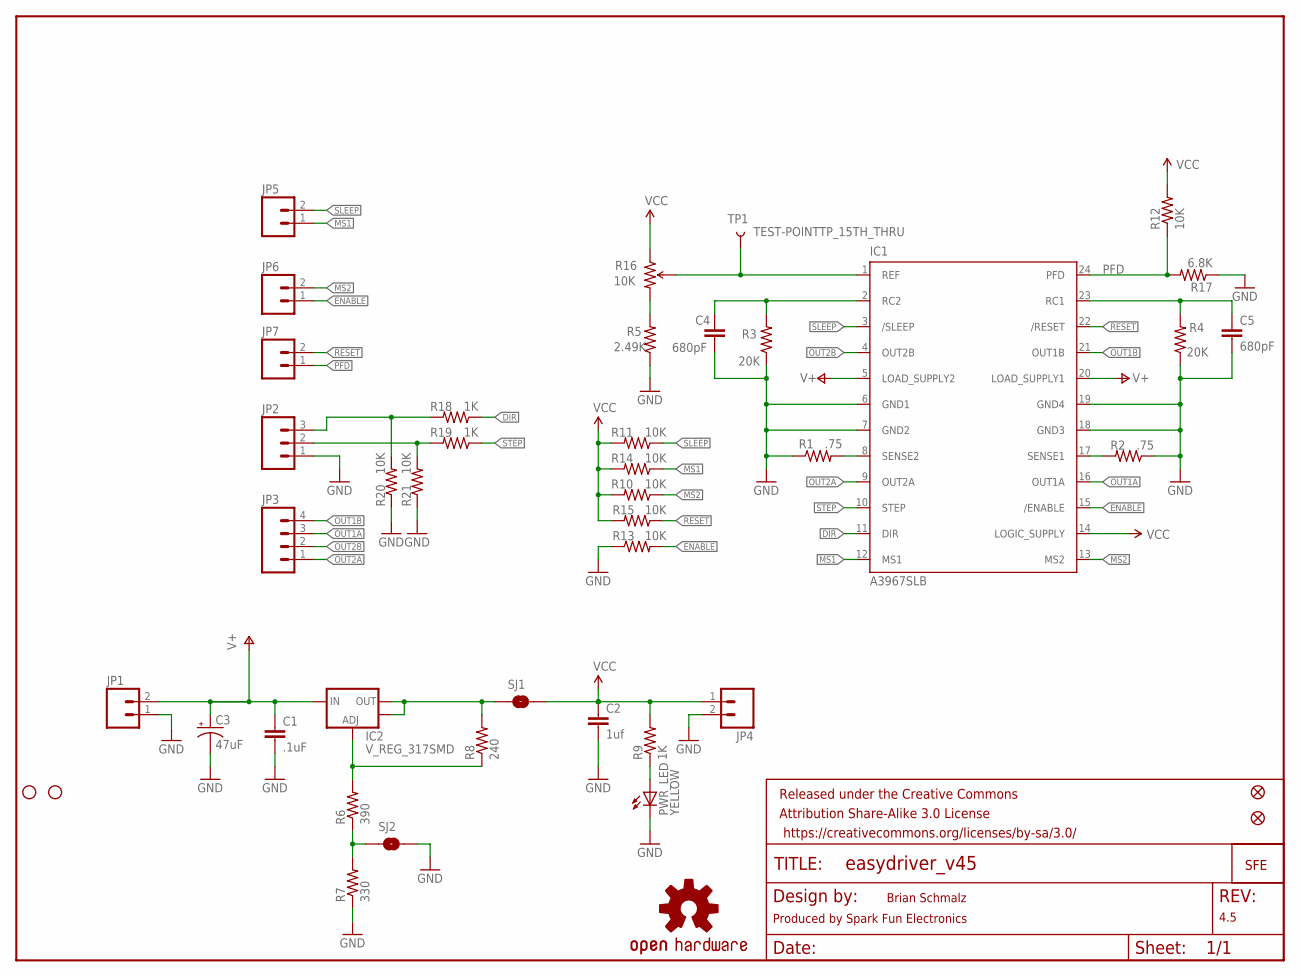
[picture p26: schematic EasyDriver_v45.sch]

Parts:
C1: .1uF; 0603-CAP
C2: 1uf; 0603-CAP
C3: 47uF; PANASONIC_D
C4, C5: 680pF; 0603-CAP
FID1, FID2: FIDUCIAL1X2; FIDUCIAL-1X2
FRAME2: FRAME-LETTER; CREATIVE_COMMONS
IC1: A3967SLB; SO24W
IC2: V_REG_317SMD; SOT223
JP1, JP4, JP5, JP6, JP7: M021X02_NO_SILK; 1X02_NO_SILK
JP2: M031X03_NO_SILK; 1X03_NO_SILK
JP3: M041X04_NO_SILK; 1X04_NO_SILK
JP8, JP9: STAND-OFF
LOGO1: OSHW-LOGOS; OSHW-LOGO-S
PWR_LED: YELLOW; LED-0603
R1, R2: .75; 0805
R3, R4: 20K; 0603-RES
R5: 2.49K; 0603-RES
R6: 390; 0603-RES
R7: 330; 0603-RES
R8: 240; 0603-RES
R9, R18, R19: 1K; 0603-RES
R10, R11, R12, R13, R14, R15, R20, R21: 10K; 0603-RES
R16: 10K; TRIMPOT-3MM-2
R17: 6.8K; 0603-RES
SJ1: SOLDERJUMPERTRACE; SJ_2S-TRACE
SJ2: SOLDERJUMPERNO; SJ_2S-NO
TP1: TEST-POINTTP_15TH_THRU; TP_15TH
U$2: LOGO-SFENEW; SFE-NEW-WEBLOGO

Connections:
5V_ALT: IC2.2 (OUT), IC2.4 (OUT), R8.2, SJ1.1
DIR: IC1.11 (DIR), R18.1
DIR_IN: JP2.3, R18.2, R20.2
ENABLE: IC1.15 (/ENABLE), JP6.1, R13.2
GND: C1.2, C2.2, C3.-, C4.2, C5.2, IC1.6 (GND1), IC1.7 (GND2), IC1.18 (GND3), IC1.19 (GND4), JP1.1, JP2.1, JP4.2, PWR_LED.C, R1.1, R2.1, R3.1, R4.1, R5.1, R7.1, R13.1, R17.1, R20.1, R21.1, SJ2.2
MS1: IC1.12 (MS1), JP5.1, R14.1
MS2: IC1.13 (MS2), JP6.2, R10.1
unnamed: IC1.8 (SENSE2), R1.2
unnamed: PWR_LED.A, R9.1
unnamed: IC1.17 (SENSE1), R2.2
unnamed: R6.1, R7.2, SJ2.1
unnamed: C4.1, IC1.2 (RC2), R3.2
unnamed: IC2.1 (ADJ), R6.2, R8.1
unnamed: C5.1, IC1.23 (RC1), R4.2
unnamed: R5.2, R16.3 (CW)
OUT1A: IC1.16 (OUT1A), JP3.3
OUT1B: IC1.21 (OUT1B), JP3.4
OUT2A: IC1.9 (OUT2A), JP3.1
OUT2B: IC1.4 (OUT2B), JP3.2
PFD: IC1.24 (PFD), JP7.1, R12.1, R17.2
RESET: IC1.22 (/RESET), JP7.2, R15.1
SLEEP: IC1.3 (/SLEEP), JP5.2, R11.1
STEP: IC1.10 (STEP), R19.1
STEP_IN: JP2.2, R19.2, R21.2
V+: C1.1, C3.+, IC1.5 (LOAD_SUPPLY2), IC1.20 (LOAD_SUPPLY1), IC2.3 (IN), JP1.2
VCC: C2.1, IC1.14 (LOGIC_SUPPLY), JP4.1, R9.2, R10.2, R11.2, R12.2, R14.2, R15.2, R16.1 (CCW), SJ1.2
VREF: IC1.1 (REF), R16.2 (WIPER), TP1.P$1

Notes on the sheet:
Brian Schmalz
Produced by Spark Fun Electronics
4.5

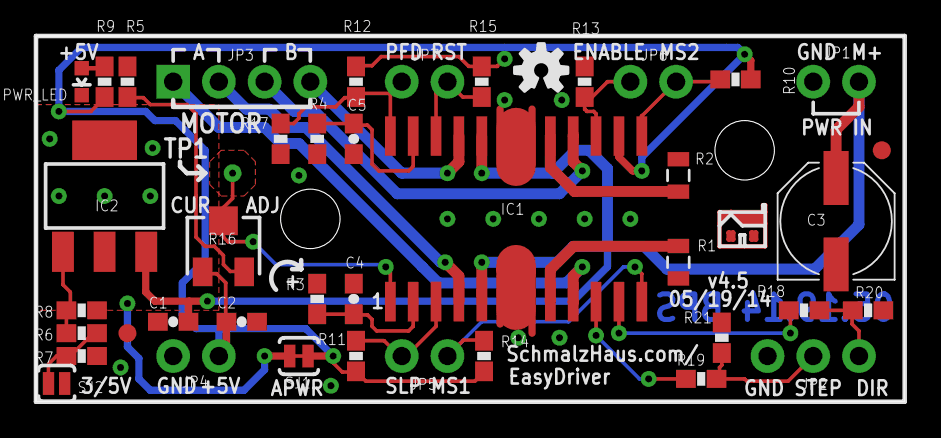
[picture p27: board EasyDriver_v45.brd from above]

Board: 2 copper layers, 48.3 x 20.3 mm, 47 parts (1 on the bottom side), 27 nets.

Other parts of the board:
U$1: SCHMALZHAUS_SMALL

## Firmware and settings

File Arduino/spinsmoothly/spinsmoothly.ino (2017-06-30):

/******************************************************************************

  Spin Table AccelStepper Big Easy Driver DIY Shield
  Author: Damon Hamm, Sculptor
  Last Updated: 2017 June 30

  A DIY Big Easy Driver shield using the Arduino Proto Shield R3.

  Modified from the original 'Spin' turtntable sketch by Tiffany Tseng
  for controlling using the Spin iOS app:
  http://spin.media.mit.edu/build
  AccelStepper driver documentation at:
  http://www.airspayce.com/mikem/arduino/AccelStepper/classAccelStepper.html
  Brian Schmalz Big Easy Driver page:
  http://www.schmalzhaus.com/BigEasyDriver/index.html

******************************************************************************/

// Pin definitions for Easy Driver on Arduino Proto Shield R3
#define pin_dirED 2
#define pin_stepED 9
/*
  // optional Easy Driver pins to control step resolution and enabled state
  #define ED_MS1 11
  #define ED_MS2 10
  #define ED_enable 8
*/
// Other declarations
#define led_power 13
#define led_mode A2

// Motor parameter variables - tweak these as necessary
int numRotations = 15; // default = 15
float rotAmt = 2600; // Distance the stepper should turn for each increment * numRotations to make a full 360 spin. Unforunately, distance seems tied to acceleration (motor_accel).
float motor_accel = 8000; // Acceleration (>0): I chose an moderately fast acceleration that doesn't shaking whatever is on top too much.
float motor_speed = 4000; // Max speed (>0): Mine caps at around 4100. Speeds exceeding max supported by the processor may result in non-linear accelerations.

#include <AccelStepper.h>
// Basic usage 'AccelStepper myStepper(AccelStepper::DRIVER, STEP_PIN_INT, DIRECTION_PIN_INT);
// 'AccelStepper::DRIVER' sets the MotorInterfaceType to use a stepper driver board with Step and Direction pins.
// If an enable line is also needed, call setEnablePin() after construction.
AccelStepper myStepper(AccelStepper::DRIVER, pin_stepED, pin_dirED);


// Variable setup
boolean rotating = false;
boolean cancelled = false;
int currentRotation = 0;
char val;
char user_input;


// Spin mobile app dependencies
#include <SoftModem.h> // library
#include <ctype.h>
// *** LIBRARY IS HARDCODED TO USE PINS D3 AND D6
// *** D3 = FSK-OUT
// *** D6 = FSK-IN
SoftModem modem; // create Softmodem object

// Button control variables
#define btn_easy 4
int buttonState = HIGH;
int lastButtonState = LOW;
long lastDebounceTime = 0;
long debounceDelay = 20;
boolean spinCreated = false;


void setup() {
  // Easy Driver pin setup
  pinMode(pin_stepED, OUTPUT);
  pinMode(pin_dirED, OUTPUT);

  myStepper.setMaxSpeed(motor_speed);
  myStepper.setAcceleration(motor_accel);

  /*
    pinMode(ED_MS1, OUTPUT);
    pinMode(ED_MS2, OUTPUT);
    pinMode(ED_enable, OUTPUT);
    resetEDPins(); //Set Easy Driver step, direction, microstep and set pins to defaults
  */
  // Button, switch & LED pin setup
  //  pinMode(ED_enable, OUTPUT);
  //  pinMode(btn_fwd, INPUT_PULLUP);
  //  pinMode(btn_rev, INPUT_PULLUP);
  pinMode(btn_easy, INPUT_PULLUP);
  pinMode(led_mode, OUTPUT);

  Serial.begin(9600); //Open Serial connection for debugging
  Serial.println();
  Serial.println("Press: 1 rotate forward, 2 reverse, 3 spin 360, 4 sim-photo, ");
  Serial.println("5 motor speed test, 6 motor accel test:");
  modem.begin(); // start Softmodem mobile audio for communicating to Spin app
}


//////////////////// MAIN CONTROL LOOP ////////////////////
void loop() {
  //  digitalWrite(ED_enable, LOW); //Pull enable pin low to allow motor control

  // Serial port control for debugging
  if (Serial.available()) {
    user_input = Serial.read(); //Read user input and trigger appropriate function
    if (user_input == '1') {
      rotate(rotAmt);
    } else if (user_input == '2') {
      rotate(-rotAmt);
    } else if (user_input == '3') {
      rotate(rotAmt * numRotations);
    } else if (user_input == '4') {
      currentRotation = 0;
      rotating = true;
      cancelled = false;
      rotateAndPhoto();
    } else if (user_input == '5') { // for calibrating the maximum motor speed
      currentRotation = 0;
      rotating = true;
      while (currentRotation < numRotations) {
        Serial.print("motor_speed = ");
        Serial.print(motor_speed, 2);
        Serial.print("    currentRotation = ");
        Serial.println(currentRotation);
        rotate(rotAmt * 6);
        motor_speed += 100;
        myStepper.setMaxSpeed(motor_speed);
        currentRotation++;
      }
    } else if (user_input == '6') { // for calibrating the maximum motor accel
      currentRotation = 0;
      rotating = true;
      while (currentRotation < numRotations) {
        Serial.print("motor_accel = ");
        Serial.print(motor_accel, 2);
        Serial.print("    currentRotation = ");
        Serial.println(currentRotation);
        rotate(rotAmt);
        delay(4000);
        motor_accel -= 200;
        myStepper.setAcceleration(motor_accel);
        currentRotation++;
      }
    } else {
      Serial.println("Invalid option entered.");
    }
  }
  if (rotating == false) {
    ledsOff();
  }

  //////////////////// Spin mobile app modem control ////////////////////
  if (modem.available ()) {
    int input = modem.read (); // Received signal from iphone
    Serial.println(input);

    if (input == 253  || input == 93) {
      // begin spin - flash LED
      Serial.println(" start ");
      modem.write(0xFC); // send confirmation signal to app (252)
      flashLEDsOnce();
      currentRotation = 0;
      rotating = true;
      cancelled = false;
      delay(1000);
    } else if (input == 251 || input == 91) {
      // stop arduino
      rotating = false;
      cancelled = true;
      spinCreated = false;
      currentRotation = 0;
      Serial.println(" stop - writing stop signal");
      modem.write(0xFE); // 254
    } else if (input == 234 || input == 74) {
      // setup signal received (for one-time setup when user first downloads app)
      flashLEDsOnce();
      modem.write(0xEC);
      rotate(rotAmt / 2);
      rotate(-rotAmt / 2);
    } else if (input == 255) {
      // spin has been created -> (used for enabling remote shutter button)
      spinCreated = true;
    }
  }

  rotateAndPhoto();


  //////////////////// EASY BUTTON STUFF ////////////////////
  int reading = digitalRead(btn_easy);
  if (reading != lastButtonState) {

    lastDebounceTime = millis();
  }

  if ((millis() - lastDebounceTime) > debounceDelay) {
    // whatever the reading is at, it's been there for longer
    // than the debounce delay, so take it as the actual current state:

    // if the button state has changed:
    if (reading != buttonState) {
      buttonState = reading;

      // only toggle the LED if the new button state is HIGH
      if (buttonState == HIGH && spinCreated) {
        Serial.println("write start to app");
        modem.write(0xFC); // send confirmation signal to app
        flashLEDsOnce();
        currentRotation = 0;
        rotating = true;
        cancelled = false;
        delay(1000);
      }
    }
  }
  lastButtonState = reading;
}
//////////////////// END MAIN LOOP ////////////////////


//////////////////// Run motor driver, take photo ////////////////////
void rotateAndPhoto() {
  if (rotating && !cancelled && currentRotation < numRotations) {
    Serial.println(currentRotation + 1);
    singleRotation();
    currentRotation++;
    takePhoto();
  } else {
    rotating = false;
    cancelled = true;
  }
}

void singleRotation() {
  rotating = true;
  ledsOn();
  rotate(rotAmt);
  ledsOff();
}

void takePhoto() {
  delay(1950);   // simple delay to capture photo in app - Future revision to include more device handshake feedback (success, fail, etc).

}

// Motor Controls
void rotate(float amt) {
  int dir = (amt > 0) ? HIGH : LOW;
  digitalWrite(pin_dirED, dir);

  myStepper.move(amt);
  myStepper.runToPosition();
}

//////////////////// System state feedback ////////////////////
// Future revision to include more expressive feedback (speed, direction, etc)
void ledsOn() {
  digitalWrite(led_mode, HIGH);
}

void ledsOff() {
  digitalWrite(led_mode, LOW);
}

void flashLEDs() {
  for (int i = 0; i < 3; i++) {
    digitalWrite(led_mode, HIGH);
    delay(300);
    digitalWrite(led_mode, LOW);
    delay(300);
  }
}

void flashLEDsOnce() {
  digitalWrite(led_mode, HIGH);
  delay(100);
  digitalWrite(led_mode, LOW);
}


/*
  //Reset Easy Driver pins to default states
  void resetEDPins()
  {
  digitalWrite(pin_stepED, LOW);
  digitalWrite(pin_dirED, LOW);
  digitalWrite(ED_MS1, LOW);
  digitalWrite(ED_MS2, LOW);
  digitalWrite(ED_enable, HIGH);
  }
*/

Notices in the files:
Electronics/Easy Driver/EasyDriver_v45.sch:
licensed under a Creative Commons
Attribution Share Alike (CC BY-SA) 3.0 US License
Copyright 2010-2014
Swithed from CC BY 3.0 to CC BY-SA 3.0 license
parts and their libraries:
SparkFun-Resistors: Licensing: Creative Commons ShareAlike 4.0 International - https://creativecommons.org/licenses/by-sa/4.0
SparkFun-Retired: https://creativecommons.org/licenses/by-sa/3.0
